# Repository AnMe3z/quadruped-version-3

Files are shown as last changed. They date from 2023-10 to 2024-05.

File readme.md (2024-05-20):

# Мобилен робот с безжично управление
## _MECHKA v3_



Целта на дипломната работа е да се създаде четирикрак робот с безжично управление.

Дипломант:     Андрей Методиев Ежков 12Г Випуск 2024

Ръководител: Владимир Иванов

В текущата репозитория е разделена на:

- hardware/ - четежи, CAD файлове и рендери
- software/ - сорс код на изработката

## hardware/

Тук се намират всички чертежи по корпуса, CAD файлове, рендери и файловете за платката:

- body/
- leg/
- motor/
- schematics/

Както и 3Д рендер на цялостния робот

## software/

Тук се намира сорс кода на проекта

- main/
- main.c
- control-app/
- app.c

main.c е софтуерът за микроконтролера. Инструкции за флашване:

```sh
cd software/main/build
chmod +x upload.sh
./upload.sh
```

app.py е GUI-то за контрол върху робота. Инструкции:

```sh
cd software/control-app/
source venv/bin/activate
python3 app.py
```

## License

Copyright 2023-2024 All rights reserved
Андрей Ежков си запазва всички права

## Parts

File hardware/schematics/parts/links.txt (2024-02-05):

https://app.ultralibrarian.com/details/e938f7e1-4622-11ed-b159-0a34d6323d74/Toshiba-Electronic-Devices-Storage-Corp-/TB67H450AFNG-EL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
https://app.ultralibrarian.com/details/ca52ef32-0283-11ed-b159-0a34d6323d74/Raspberry-Pi/SC0917?uid=129877558
https://grabcad.com/library/xl4005-1
https://grabcad.com/library/raspberry-pi-pico-w-rp2040-no-pins-pins-and-socketed-1
https://app.ultralibrarian.com/details/f9dd745b-0f3c-11ec-9033-0a34d6323d74/Amass/XT60PW-F?open=backlink
https://github.com/sarfat96/KiCad/blob/master/library/Module/XL4005/XL4005_DC-DC.lib
https://app.ultralibrarian.com/details/4b3352ef-44e3-11eb-9033-0a34d6323d74/JST/B7B-XH-A-LF-SN-?uid=7501607
https://app.ultralibrarian.com/details/34553c35-1aab-11e9-ab3a-0a3560a4cccc/JST/B2B-EH-A-LF-SN-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

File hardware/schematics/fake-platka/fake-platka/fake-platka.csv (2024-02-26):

Source: | /home/andrey-shefa/Documents/repos/quadruped-version-3/hardware/schematics/fake-platka/fake-platka/fake-platka.kicad_sch
Date: | Fri 23 Feb 2024 09:56:27 AM EET
Tool: | Eeschema 6.0.11+dfsg-1
Generator: | /usr/share/kicad/plugins/bom_csv_grouped_by_value_with_fp.py
Component Count: | 88
Ref | Qnty | Value | Cmp name | Footprint | Description | Vendor
D1, D2, D3, D4, D5, D6, D7, D8, | 8 | 1N4001 | DIODE | Diode_THT:D_DO-41_SOD81_P7.62mm_Horizontal | Diode symbol for simulation only. Pin order incompatible with official kicad footprints
J1, J2, J7, J8, J14, J15, J21, J22, J28, J29, | 10 | XT60PW-F | XT60PW-F | quadruped-lib-footprints:CONN_XT60PW-F_AMA
J3, J4, J5, J6, J9, J10, J11, J12, J13, J16, J17, J18, J19, J20, J23, J24, J25, J26, J27, J30, | 20 | B2B-EH-A | B2B-EH-A_LFSN | quadruped-lib-footprints:CONN_B2B-EH-A LFSN_JST
R1, R2, R7, R8, R9, R10, R16, R17, R18, R19, R25, R26, R27, R28, R34, R35, R36, R37, | 18 | R1 | R | Resistor_THT:R_Axial_DIN0207_L6.3mm_D2.5mm_P10.16mm_Horizontal | Resistor
R3, R4, R6, R11, R12, R13, R15, R20, R21, R22, R24, R29, R30, R31, R33, R38, | 16 | 5K | R | Resistor_THT:R_Axial_DIN0207_L6.3mm_D2.5mm_P10.16mm_Horizontal | Resistor
R5, R14, R23, R32, | 4 | 150R | R | Resistor_THT:R_Axial_DIN0207_L6.3mm_D2.5mm_P10.16mm_Horizontal | Resistor
U1, U2, | 2 | XL4005 | XL4005 | quadruped-lib-footprints:XL4005_DC-DC
U3, U4, | 2 | SC0915-pico-w-board | SC0915-pico-w-board | quadruped-lib-footprints:RPi_PicoW_SMD_TH
U5, U6, U7, U8, U9, U10, U11, U12, | 8 | TB67H450AFNG_EL | TB67H450AFNG_EL | quadruped-lib-footprints:P-HSOP8-0405-1.27-002_TOS

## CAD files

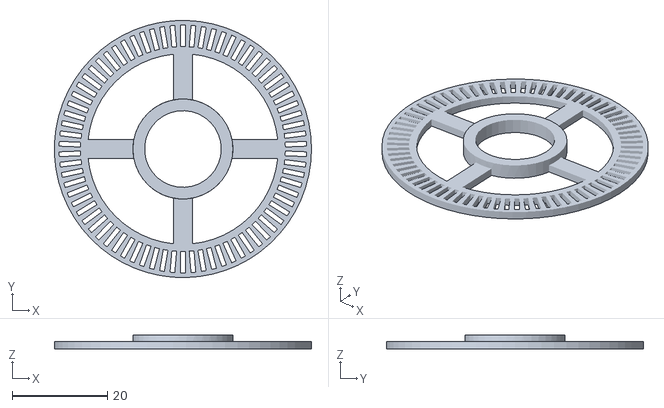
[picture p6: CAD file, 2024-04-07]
hardware/leg/encoder/wingEncoder/wingFullBelt74.stl
54.0 x 54.0 x 3.00

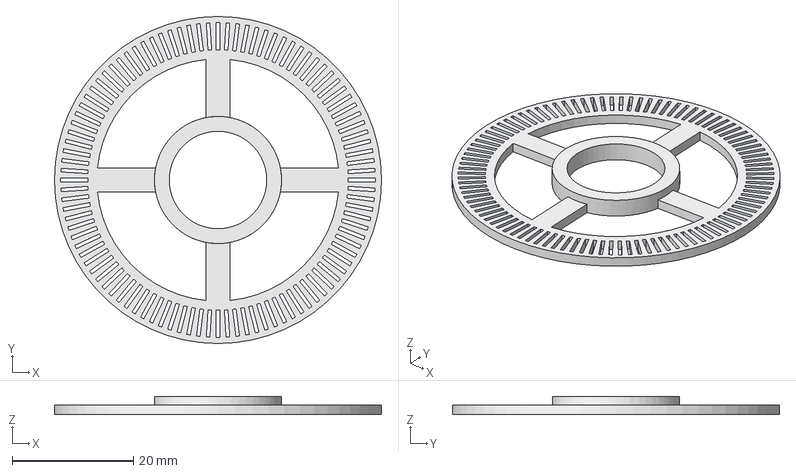
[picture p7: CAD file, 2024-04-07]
hardware/leg/encoder/wingEncoder/wingFullBelt.FCStd
54.0 x 54.0 x 3.00 mm

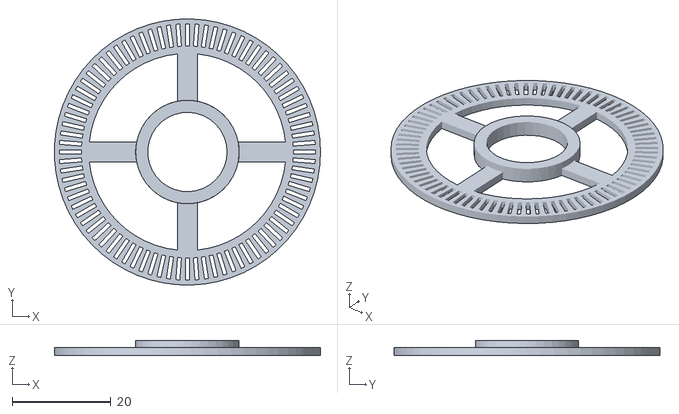
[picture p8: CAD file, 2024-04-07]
hardware/leg/encoder/wingEncoder/wingFullBelt84.stl
54.0 x 54.0 x 3.00

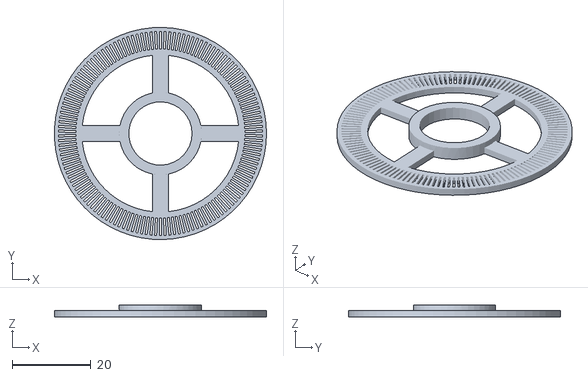
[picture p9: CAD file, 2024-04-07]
hardware/leg/encoder/wingEncoder/wingFullBelt134.stl
54.0 x 54.0 x 3.00

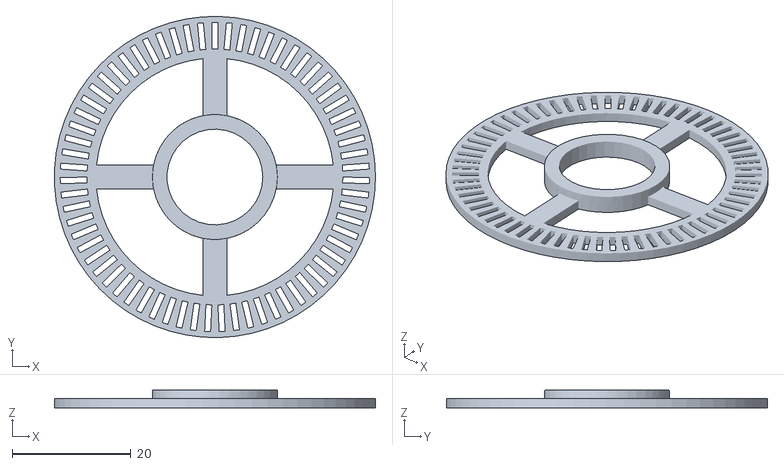
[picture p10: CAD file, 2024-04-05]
hardware/leg/encoder/wingEncoder/wingFullBelt67.stl
54.0 x 54.0 x 3.00

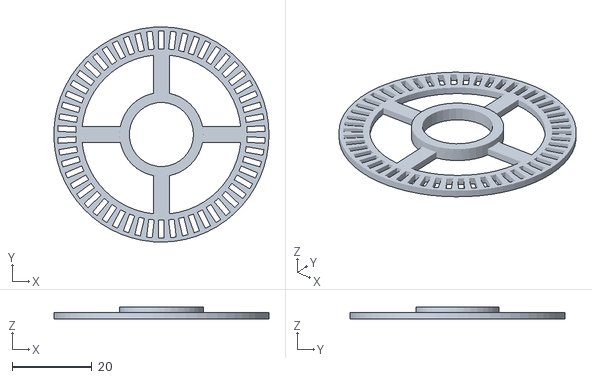
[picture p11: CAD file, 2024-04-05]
hardware/leg/encoder/wingEncoder/wingFullBelt54.stl
54.0 x 54.0 x 3.00

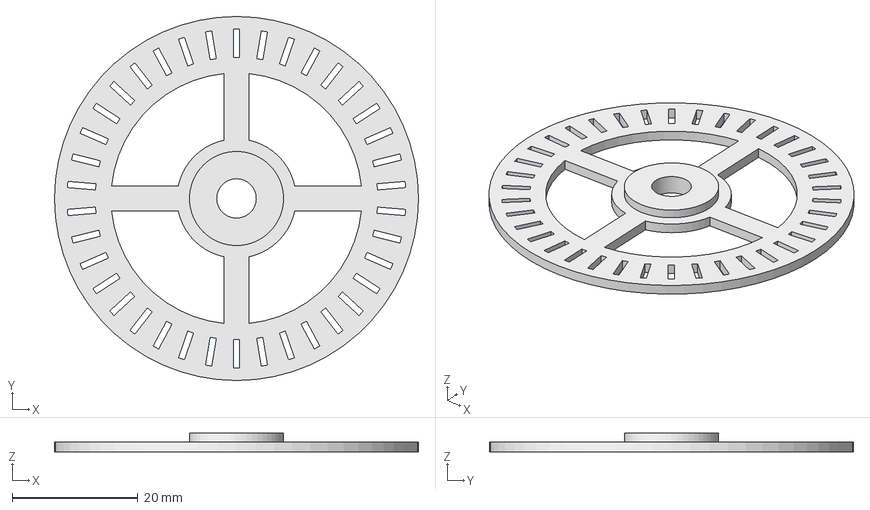
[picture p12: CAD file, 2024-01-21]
hardware/leg/encoder/wingEncoder/wingFull.FCStd
58.0 x 58.0 x 3.00 mm

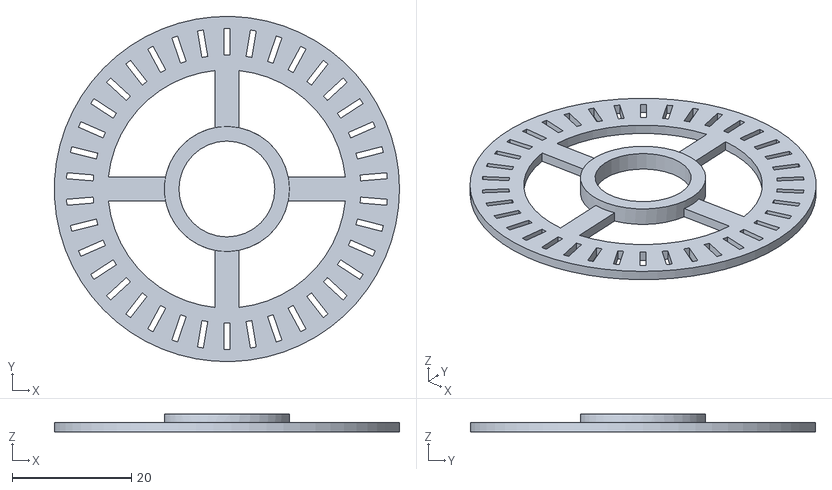
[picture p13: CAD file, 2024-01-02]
hardware/leg/encoder/wingEncoder/wingFullBelt38.stl
58.0 x 58.0 x 3.00

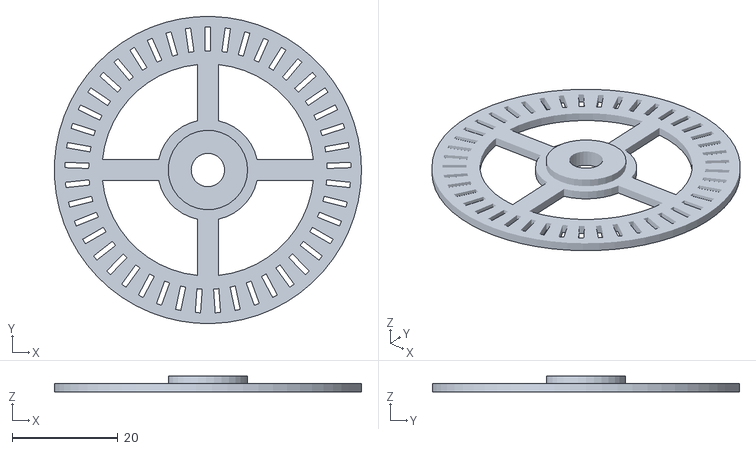
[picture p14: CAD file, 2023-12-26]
hardware/leg/encoder/wingEncoder/wingFull45.stl
58.0 x 58.0 x 3.00

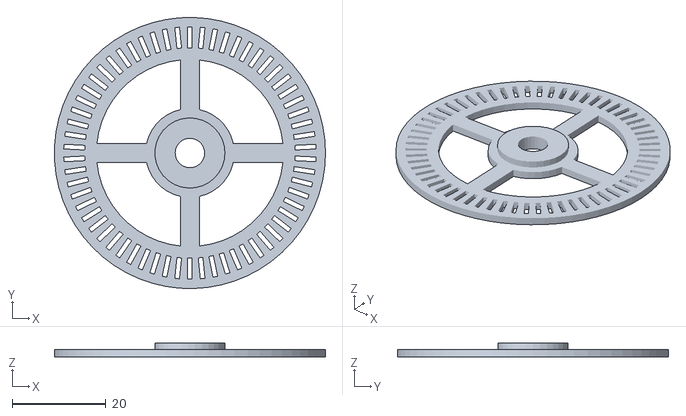
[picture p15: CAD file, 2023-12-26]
hardware/leg/encoder/wingEncoder/wingFull62.stl
58.0 x 58.0 x 3.00

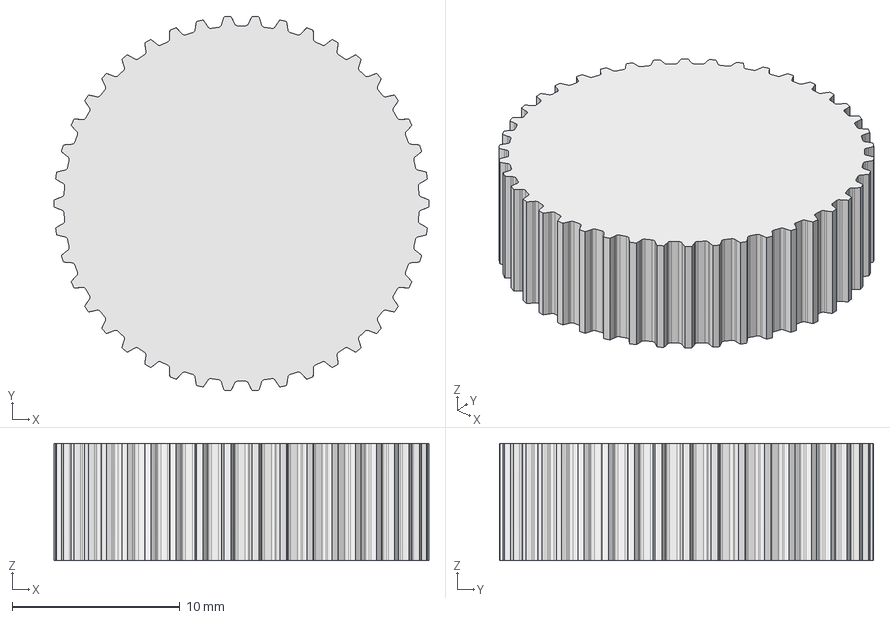
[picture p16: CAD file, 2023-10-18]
belt-gear.FCStd
22.4 x 22.4 x 7.00 mm

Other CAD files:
hardware/leg/encoder/wingEncoder/wingFullBelt100.stl
hardware/leg/knee/mainpoints.FCStd
hardware/leg/encoder/wingEncoder/wingFullBelt38Cut.stl
hardware/leg/encoder/wingEncoder/wingFull37.stl
hardware/leg/encoder/wingEncoder/wingFull38.stl
hardware/leg/encoder/wingEncoder/wingFull36.stl
hardware/leg/encoder/wingEncoder/wingFull34.stl
encoder/base.FCStd
encoder/encoder-wheels/encoder-wheel-8-1mm.FCStd
encoder/encoder-wheels/encoder-wheel-8-1mm.stl
encoder/encoder-wheels/encoder-wheel-8-3mm.FCStd
encoder/encoder-wheels/encoder-wheel-8-3mm.stl
encoder/encoder-wheels/encoder-wheel.FCStd
encoder/encoder-wheels/ew-16-1mm.FCStd
encoder/encoder-wheels/ew-16-1mm.stl
encoder/gears/encoder-gear-Body.stl
encoder/gears/encoder-gear.FCStd
encoder/gears/mid-gear-arm-Body.stl
encoder/gears/mid-gear-arm.FCStd
encoder/gears/middle-gear-Body.stl
encoder/gears/middle-gear.FCStd
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

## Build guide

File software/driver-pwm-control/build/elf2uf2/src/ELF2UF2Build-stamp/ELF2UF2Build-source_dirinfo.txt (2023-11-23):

# This is a generated file and its contents are an internal implementation detail.
# The download step will be re-executed if anything in this file changes.
# No other meaning or use of this file is supported.

method=source_dir
command=
source_dir=/home/andrey-shefa/pico/pico-sdk/tools/elf2uf2
work_dir=

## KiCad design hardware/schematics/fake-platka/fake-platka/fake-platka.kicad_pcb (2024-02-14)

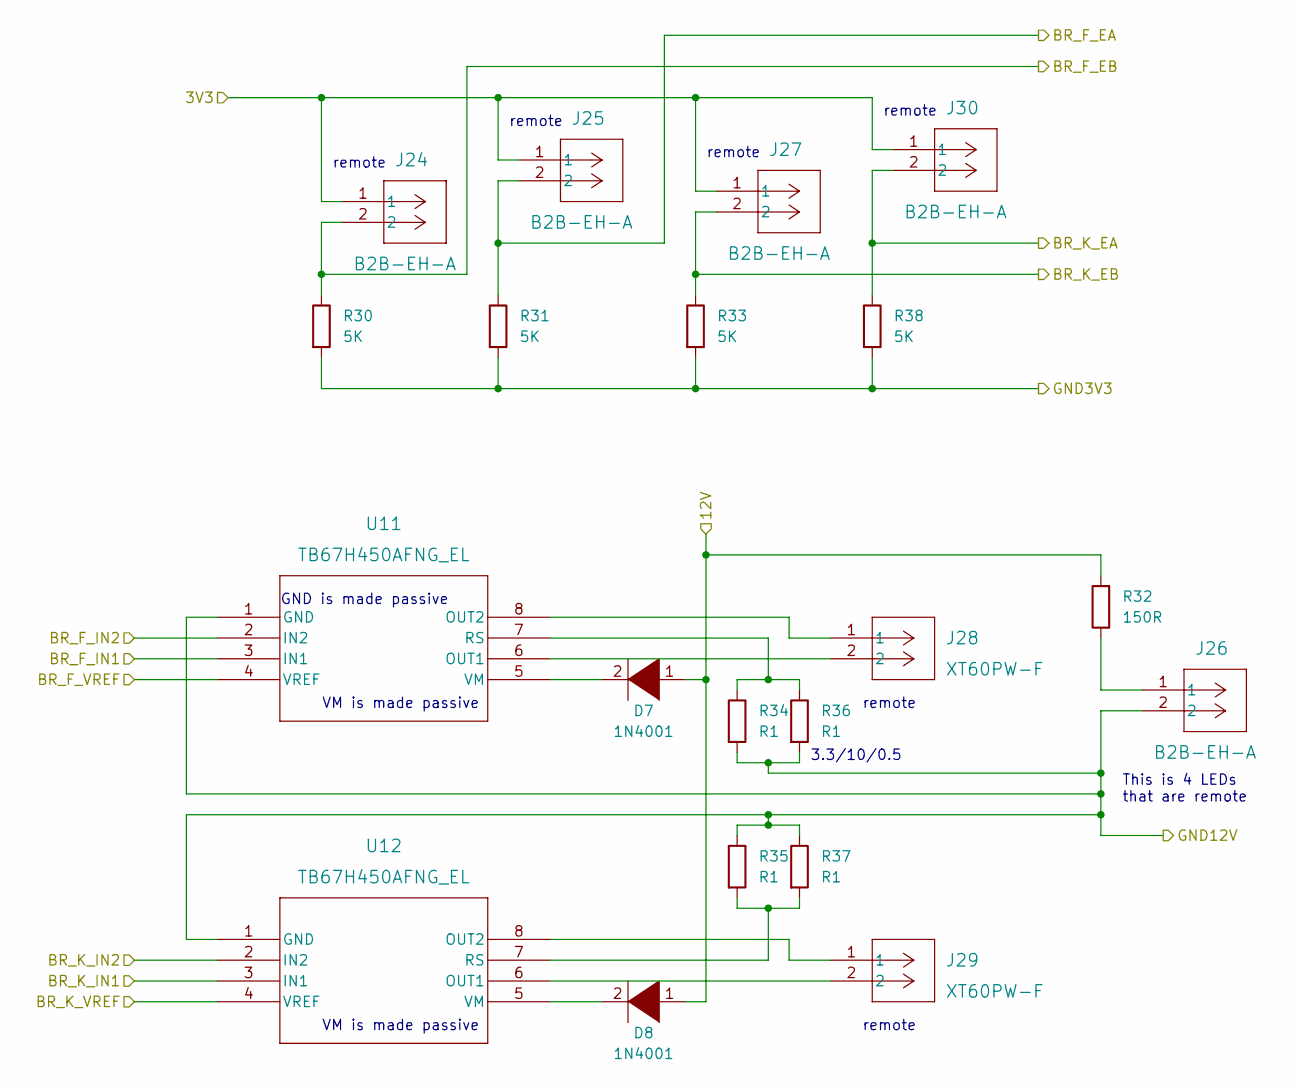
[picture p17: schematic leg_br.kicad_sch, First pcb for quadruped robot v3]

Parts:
D7, D8: 1N4001; D_DO-41_SOD81_P7.62mm_Horizontal
J24, J25, J26, J27, J30: B2B-EH-A; CONN_B2B-EH-A LFSN_JST
J28, J29: XT60PW-F; CONN_XT60PW-F_AMA
R30, R31, R33, R38: 5K; R_Axial_DIN0207_L6.3mm_D2.5mm_P10.16mm_Horizontal
R32: 150R; R_Axial_DIN0207_L6.3mm_D2.5mm_P10.16mm_Horizontal
R34, R35, R36, R37: R1; R_Axial_DIN0207_L6.3mm_D2.5mm_P10.16mm_Horizontal
U11, U12: TB67H450AFNG_EL; P-HSOP8-0405-1.27-002_TOS

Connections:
/Left Controller /3V3: J24.1, J25.1, J27.1, J30.1; also elsewhere on the board
/Left Controller /GND3V3: R30.2, R31.2, R33.2, R38.2; also elsewhere on the board
/Leg Back Left/12V: D7.1 (K), D8.1 (K), R32.2; also elsewhere on the board
/Leg Back Right/BR_F_EA: J25.2, R31.1; also elsewhere on the board
/Leg Back Right/BR_F_EB: J24.2, R30.1; also elsewhere on the board
/Leg Back Right/BR_F_IN1: U11.3 (IN1); also elsewhere on the board
/Leg Back Right/BR_F_IN2: U11.2 (IN2); also elsewhere on the board
/Leg Back Right/BR_F_VREF: U11.4 (VREF), U12.4 (VREF); also elsewhere on the board
/Leg Back Right/BR_K_EA: J30.2, R38.1; also elsewhere on the board
/Leg Back Right/BR_K_EB: J27.2, R33.1; also elsewhere on the board
/Leg Back Right/BR_K_IN1: U12.3 (IN1); also elsewhere on the board
/Leg Back Right/BR_K_IN2: U12.2 (IN2); also elsewhere on the board
/Leg Back Right/GND12V: J26.2, R34.2, R35.1, R36.2, R37.1, U11.1 (GND), U12.1 (GND); also elsewhere on the board
unnamed: D7.2 (A), U11.5 (VM)
unnamed: D8.2 (A), U12.5 (VM)
unnamed: J26.1, R32.1
unnamed: J28.1, U11.8 (OUT2)
unnamed: J28.2, U11.6 (OUT1)
unnamed: J29.1, U12.8 (OUT2)
unnamed: J29.2, U12.6 (OUT1)
unnamed: R34.1, R36.1, U11.7 (RS)
unnamed: R35.2, R37.2, U12.7 (RS)

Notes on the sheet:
GND is made passive
remote
This is 4 LEDs that are remote
VM is made passive
3.3/10/0.5

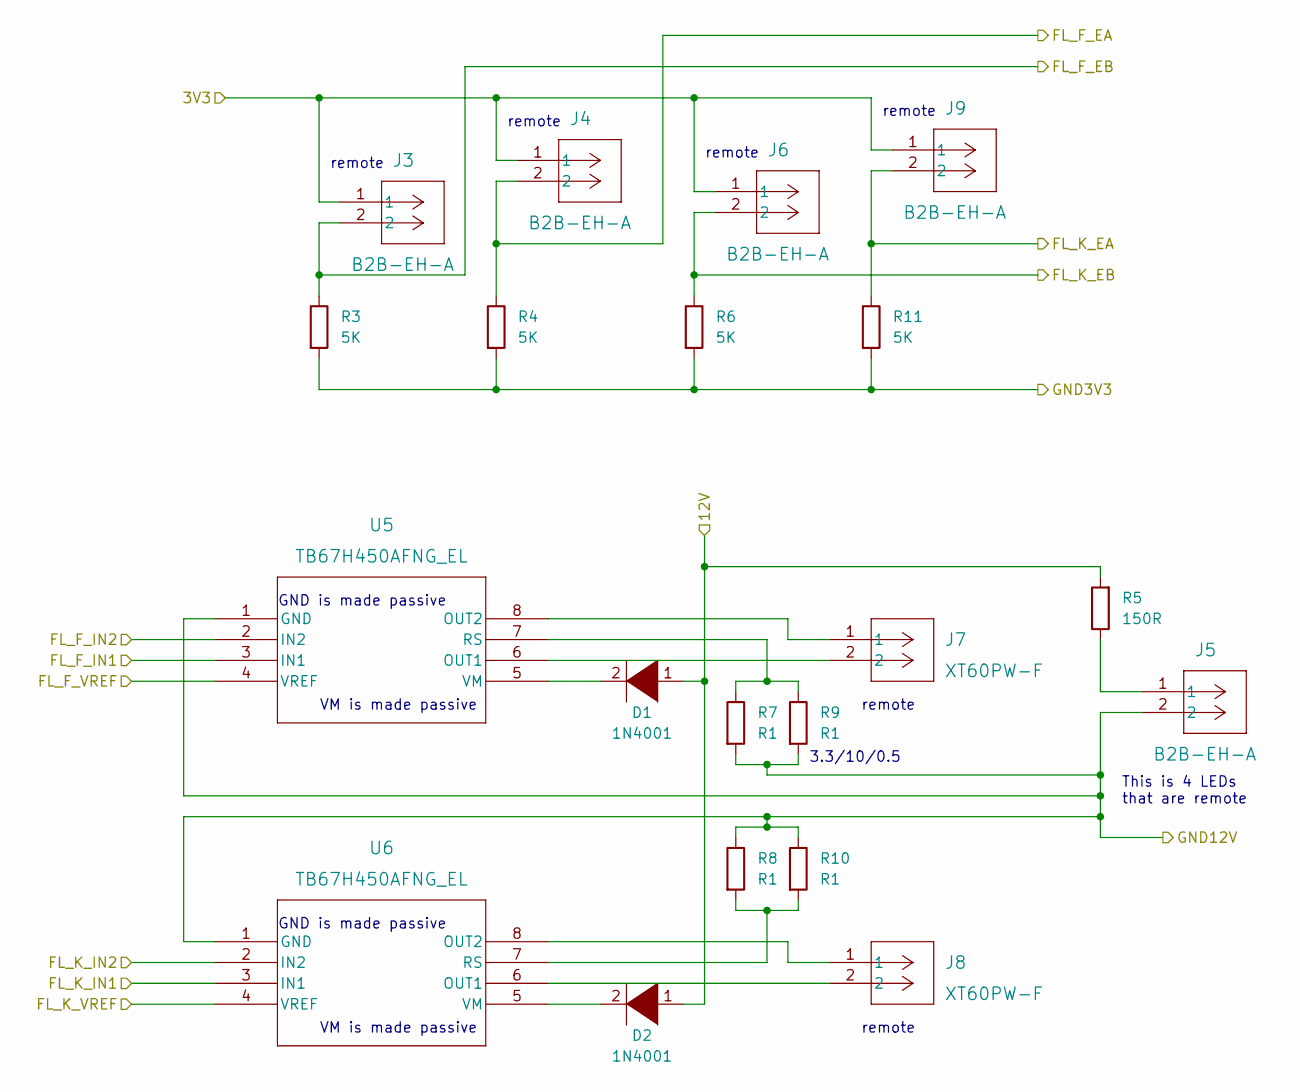
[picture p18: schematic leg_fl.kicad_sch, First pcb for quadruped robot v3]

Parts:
D1, D2: 1N4001; D_DO-41_SOD81_P7.62mm_Horizontal
J3, J4, J5, J6, J9: B2B-EH-A; CONN_B2B-EH-A LFSN_JST
J7, J8: XT60PW-F; CONN_XT60PW-F_AMA
R3, R4, R6, R11: 5K; R_Axial_DIN0207_L6.3mm_D2.5mm_P10.16mm_Horizontal
R5: 150R; R_Axial_DIN0207_L6.3mm_D2.5mm_P10.16mm_Horizontal
R7, R8, R9, R10: R1; R_Axial_DIN0207_L6.3mm_D2.5mm_P10.16mm_Horizontal
U5, U6: TB67H450AFNG_EL; P-HSOP8-0405-1.27-002_TOS

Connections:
/Left Controller /3V3: J3.1, J4.1, J6.1, J9.1; also elsewhere on the board
/Left Controller /3V3_VREF: U5.4 (VREF), U6.4 (VREF); also elsewhere on the board
/Left Controller /FL_F_EA: J4.2, R4.1; also elsewhere on the board
/Left Controller /FL_F_EB: J3.2, R3.1; also elsewhere on the board
/Left Controller /FL_F_IN1: U5.3 (IN1); also elsewhere on the board
/Left Controller /FL_F_IN2: U5.2 (IN2); also elsewhere on the board
/Left Controller /FL_K_EA: J9.2, R11.1; also elsewhere on the board
/Left Controller /FL_K_EB: J6.2, R6.1; also elsewhere on the board
/Left Controller /FL_K_IN1: U6.3 (IN1); also elsewhere on the board
/Left Controller /FL_K_IN2: U6.2 (IN2); also elsewhere on the board
/Left Controller /GND3V3: R3.2, R4.2, R6.2, R11.2; also elsewhere on the board
/Leg Back Left/12V: D1.1 (K), D2.1 (K), J5.2, R5.2, R7.2, R8.1, R9.2, R10.1, U5.1 (GND), U6.1 (GND); also elsewhere on the board
unnamed: D1.2 (A), U5.5 (VM)
unnamed: D2.2 (A), U6.5 (VM)
unnamed: J5.1, R5.1
unnamed: J7.1, U5.8 (OUT2)
unnamed: J7.2, U5.6 (OUT1)
unnamed: J8.1, U6.8 (OUT2)
unnamed: J8.2, U6.6 (OUT1)
unnamed: R7.1, R9.1, U5.7 (RS)
unnamed: R8.2, R10.2, U6.7 (RS)

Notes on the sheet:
remote
VM is made passive
GND is made passive
This is 4 LEDs that are remote
3.3/10/0.5

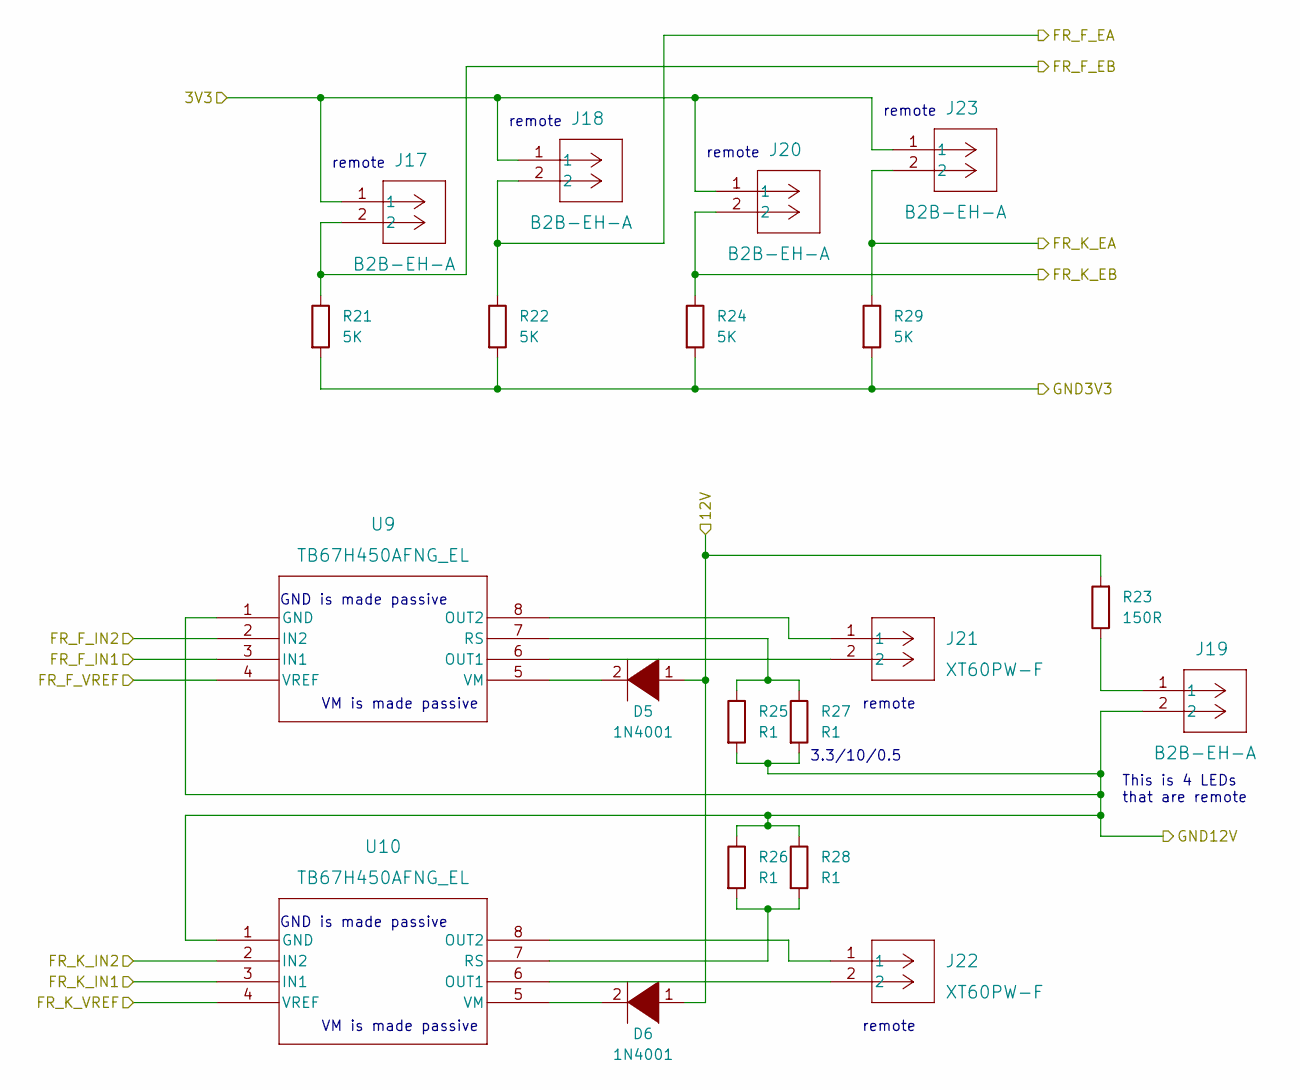
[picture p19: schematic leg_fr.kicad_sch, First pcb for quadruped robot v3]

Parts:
D5, D6: 1N4001; D_DO-41_SOD81_P7.62mm_Horizontal
J17, J18, J19, J20, J23: B2B-EH-A; CONN_B2B-EH-A LFSN_JST
J21, J22: XT60PW-F; CONN_XT60PW-F_AMA
R21, R22, R24, R29: 5K; R_Axial_DIN0207_L6.3mm_D2.5mm_P10.16mm_Horizontal
R23: 150R; R_Axial_DIN0207_L6.3mm_D2.5mm_P10.16mm_Horizontal
R25, R26, R27, R28: R1; R_Axial_DIN0207_L6.3mm_D2.5mm_P10.16mm_Horizontal
U9, U10: TB67H450AFNG_EL; P-HSOP8-0405-1.27-002_TOS

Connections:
/Left Controller /3V3: J17.1, J18.1, J20.1, J23.1; also elsewhere on the board
/Left Controller /GND3V3: R21.2, R22.2, R24.2, R29.2; also elsewhere on the board
/Leg Back Left/12V: D5.1 (K), D6.1 (K), R23.2; also elsewhere on the board
/Leg Back Right/BR_F_VREF: U9.4 (VREF), U10.4 (VREF); also elsewhere on the board
/Leg Back Right/GND12V: J19.2, R25.2, R26.1, R27.2, R28.1, U9.1 (GND), U10.1 (GND); also elsewhere on the board
/Leg Front Right/FR_F_EA: J18.2, R22.1; also elsewhere on the board
/Leg Front Right/FR_F_EB: J17.2, R21.1; also elsewhere on the board
/Leg Front Right/FR_F_IN1: U9.3 (IN1); also elsewhere on the board
/Leg Front Right/FR_F_IN2: U9.2 (IN2); also elsewhere on the board
/Leg Front Right/FR_K_EA: J23.2, R29.1; also elsewhere on the board
/Leg Front Right/FR_K_EB: J20.2, R24.1; also elsewhere on the board
/Leg Front Right/FR_K_IN1: U10.3 (IN1); also elsewhere on the board
/Leg Front Right/FR_K_IN2: U10.2 (IN2); also elsewhere on the board
unnamed: D5.2 (A), U9.5 (VM)
unnamed: D6.2 (A), U10.5 (VM)
unnamed: J21.1, U9.8 (OUT2)
unnamed: J21.2, U9.6 (OUT1)
unnamed: J22.1, U10.8 (OUT2)
unnamed: J22.2, U10.6 (OUT1)
unnamed: J19.1, R23.1
unnamed: R25.1, R27.1, U9.7 (RS)
unnamed: R26.2, R28.2, U10.7 (RS)

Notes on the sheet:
This is 4 LEDs that are remote
GND is made passive
3.3/10/0.5
remote
VM is made passive

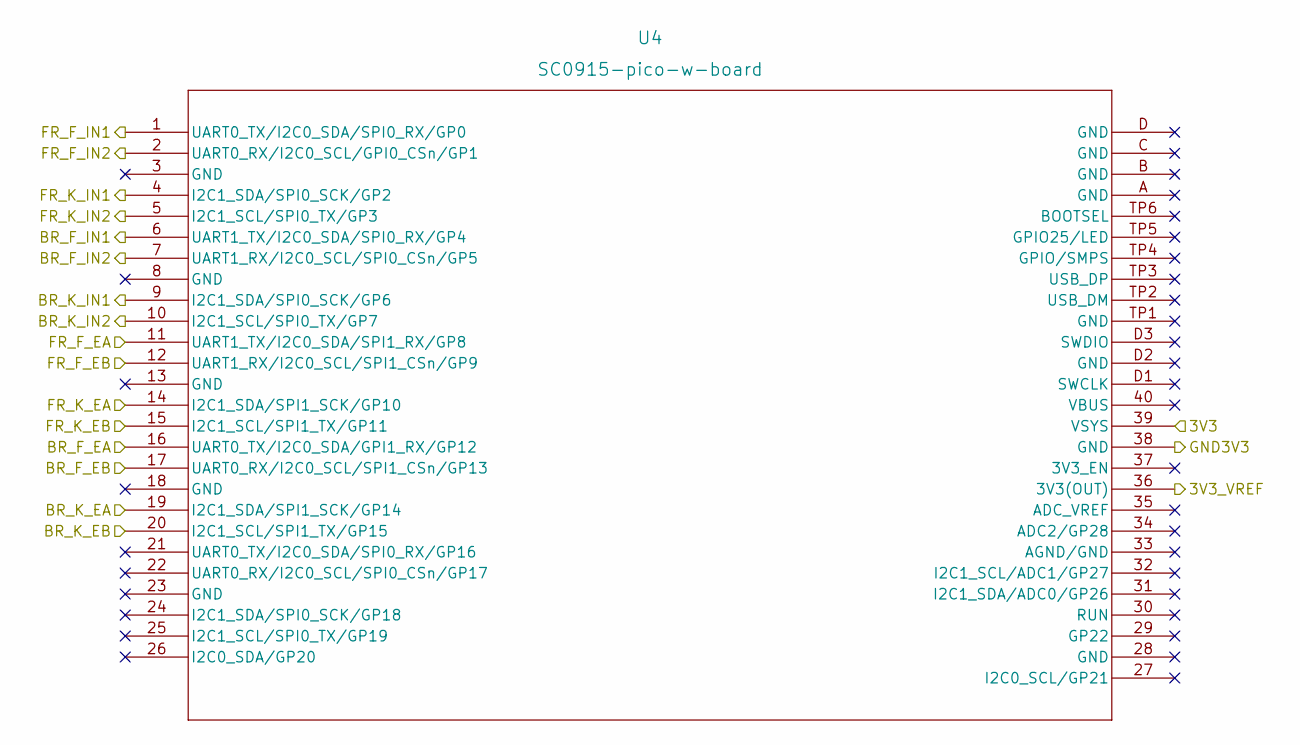
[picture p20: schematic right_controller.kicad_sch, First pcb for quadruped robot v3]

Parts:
U4: SC0915-pico-w-board; RPi_PicoW_SMD_TH

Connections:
/Left Controller /3V3: U4.39 (VSYS); also elsewhere on the board
/Left Controller /GND3V3: U4.38 (GND); also elsewhere on the board
/Leg Back Right/BR_F_EA: U4.16 (UART0_TX/I2C0_SDA/GPI1_RX/GP12); also elsewhere on the board
/Leg Back Right/BR_F_EB: U4.17 (UART0_RX/I2C0_SCL/SPI1_CSn/GP13); also elsewhere on the board
/Leg Back Right/BR_F_IN1: U4.6 (UART1_TX/I2C0_SDA/SPI0_RX/GP4); also elsewhere on the board
/Leg Back Right/BR_F_IN2: U4.7 (UART1_RX/I2C0_SCL/SPI0_CSn/GP5); also elsewhere on the board
/Leg Back Right/BR_F_VREF: U4.36 (3V3(OUT)); also elsewhere on the board
/Leg Back Right/BR_K_EA: U4.19 (I2C1_SDA/SPI1_SCK/GP14); also elsewhere on the board
/Leg Back Right/BR_K_EB: U4.20 (I2C1_SCL/SPI1_TX/GP15); also elsewhere on the board
/Leg Back Right/BR_K_IN1: U4.9 (I2C1_SDA/SPI0_SCK/GP6); also elsewhere on the board
/Leg Back Right/BR_K_IN2: U4.10 (I2C1_SCL/SPI0_TX/GP7); also elsewhere on the board
/Leg Front Right/FR_F_EA: U4.11 (UART1_TX/I2C0_SDA/SPI1_RX/GP8); also elsewhere on the board
/Leg Front Right/FR_F_EB: U4.12 (UART1_RX/I2C0_SCL/SPI1_CSn/GP9); also elsewhere on the board
/Leg Front Right/FR_F_IN1: U4.1 (UART0_TX/I2C0_SDA/SPI0_RX/GP0); also elsewhere on the board
/Leg Front Right/FR_F_IN2: U4.2 (UART0_RX/I2C0_SCL/GPI0_CSn/GP1); also elsewhere on the board
/Leg Front Right/FR_K_EA: U4.14 (I2C1_SDA/SPI1_SCK/GP10); also elsewhere on the board
/Leg Front Right/FR_K_EB: U4.15 (I2C1_SCL/SPI1_TX/GP11); also elsewhere on the board
/Leg Front Right/FR_K_IN1: U4.4 (I2C1_SDA/SPI0_SCK/GP2); also elsewhere on the board
/Leg Front Right/FR_K_IN2: U4.5 (I2C1_SCL/SPI0_TX/GP3); also elsewhere on the board

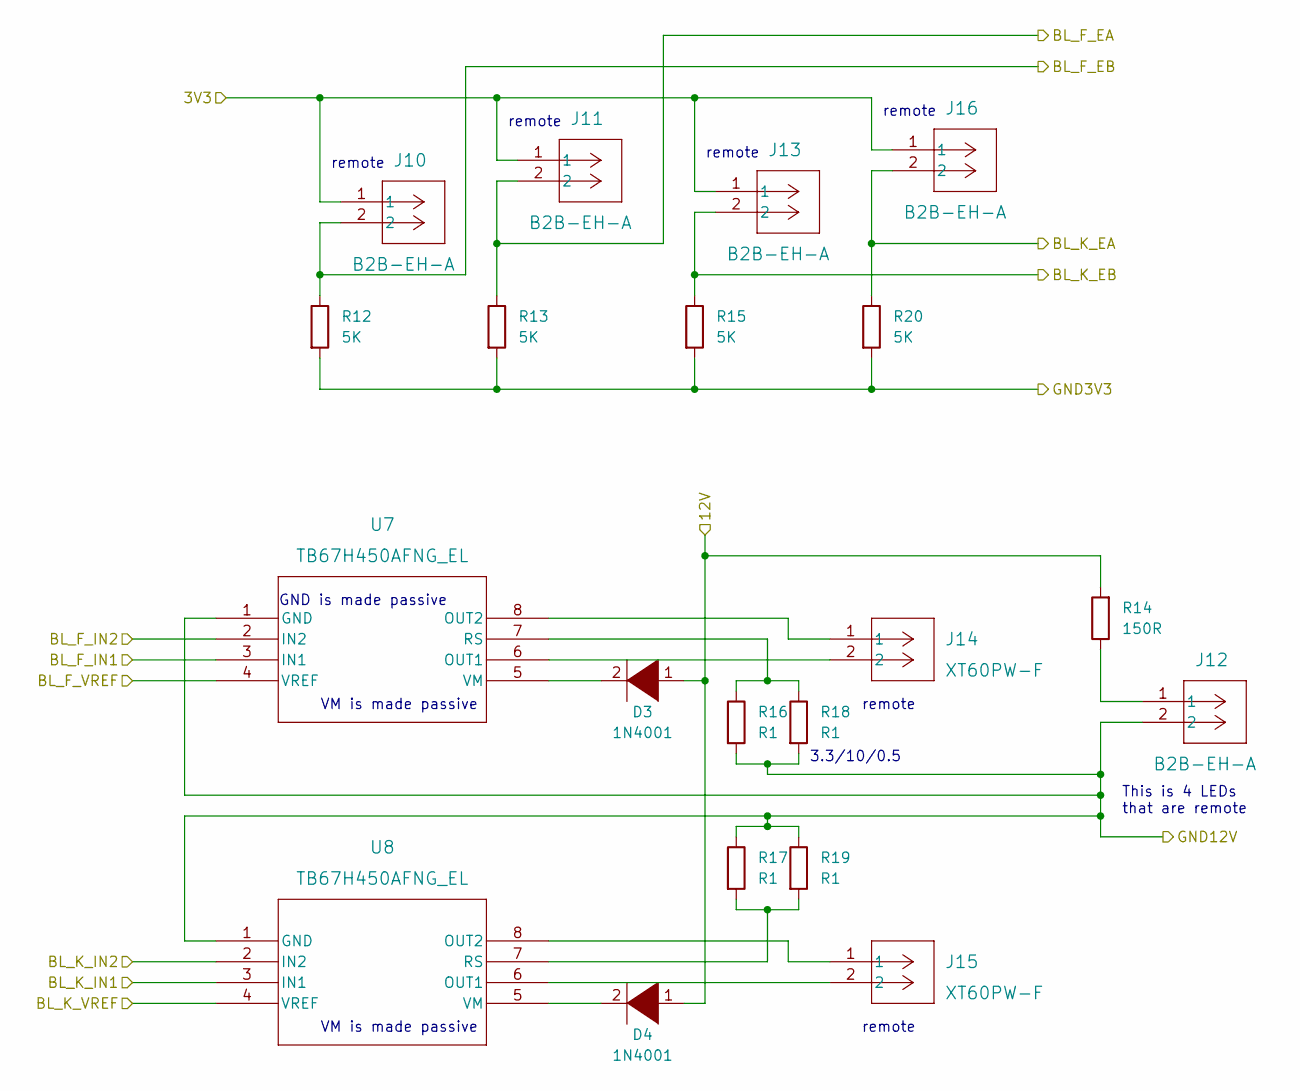
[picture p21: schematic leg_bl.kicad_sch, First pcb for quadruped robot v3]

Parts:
D3, D4: 1N4001; D_DO-41_SOD81_P7.62mm_Horizontal
J10, J11, J12, J13, J16: B2B-EH-A; CONN_B2B-EH-A LFSN_JST
J14, J15: XT60PW-F; CONN_XT60PW-F_AMA
R12, R13, R15, R20: 5K; R_Axial_DIN0207_L6.3mm_D2.5mm_P10.16mm_Horizontal
R14: 150R; R_Axial_DIN0207_L6.3mm_D2.5mm_P10.16mm_Horizontal
R16, R17, R18, R19: R1; R_Axial_DIN0207_L6.3mm_D2.5mm_P10.16mm_Horizontal
U7, U8: TB67H450AFNG_EL; P-HSOP8-0405-1.27-002_TOS

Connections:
/Left Controller /3V3: J10.1, J11.1, J13.1, J16.1; also elsewhere on the board
/Left Controller /3V3_VREF: U7.4 (VREF), U8.4 (VREF); also elsewhere on the board
/Left Controller /BL_F_EA: J11.2, R13.1; also elsewhere on the board
/Left Controller /BL_F_EB: J10.2, R12.1; also elsewhere on the board
/Left Controller /BL_F_IN1: U7.3 (IN1); also elsewhere on the board
/Left Controller /BL_F_IN2: U7.2 (IN2); also elsewhere on the board
/Left Controller /BL_K_EA: J16.2, R20.1; also elsewhere on the board
/Left Controller /BL_K_EB: J13.2, R15.1; also elsewhere on the board
/Left Controller /BL_K_IN1: U8.3 (IN1); also elsewhere on the board
/Left Controller /BL_K_IN2: U8.2 (IN2); also elsewhere on the board
/Left Controller /GND3V3: R12.2, R13.2, R15.2, R20.2; also elsewhere on the board
/Leg Back Left/12V: D3.1 (K), D4.1 (K), J12.2, R14.2, R16.2, R17.1, R18.2, R19.1, U7.1 (GND), U8.1 (GND); also elsewhere on the board
unnamed: D3.2 (A), U7.5 (VM)
unnamed: D4.2 (A), U8.5 (VM)
unnamed: J14.1, U7.8 (OUT2)
unnamed: J14.2, U7.6 (OUT1)
unnamed: J15.1, U8.8 (OUT2)
unnamed: J15.2, U8.6 (OUT1)
unnamed: J12.1, R14.1
unnamed: R16.1, R18.1, U7.7 (RS)
unnamed: R17.2, R19.2, U8.7 (RS)

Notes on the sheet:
remote
VM is made passive
GND is made passive
3.3/10/0.5
This is 4 LEDs that are remote

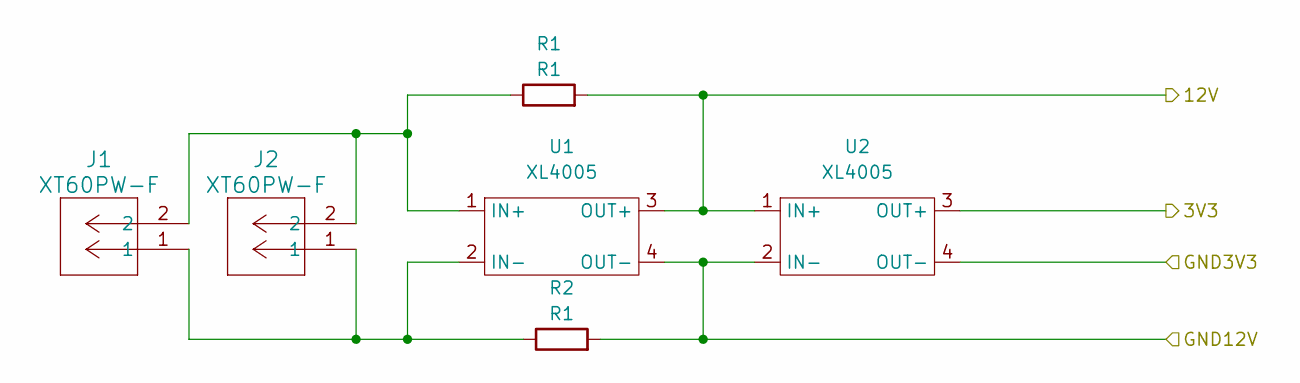
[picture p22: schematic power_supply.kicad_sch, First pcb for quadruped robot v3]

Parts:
J1, J2: XT60PW-F; CONN_XT60PW-F_AMA
R1, R2: R1; R_Axial_DIN0207_L6.3mm_D2.5mm_P10.16mm_Horizontal
U1, U2: XL4005; XL4005_DC-DC

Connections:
/Left Controller /3V3: U2.3 (OUT+); also elsewhere on the board
/Left Controller /GND3V3: U2.4 (OUT-); also elsewhere on the board
/Leg Back Left/12V: R1.2, U1.3 (OUT+), U2.1 (IN+); also elsewhere on the board
/Leg Back Right/GND12V: R2.2, U1.4 (OUT-), U2.2 (IN-); also elsewhere on the board
unnamed: J1.1, J2.1, R2.1, U1.2 (IN-)
unnamed: J1.2, J2.2, R1.1, U1.1 (IN+)

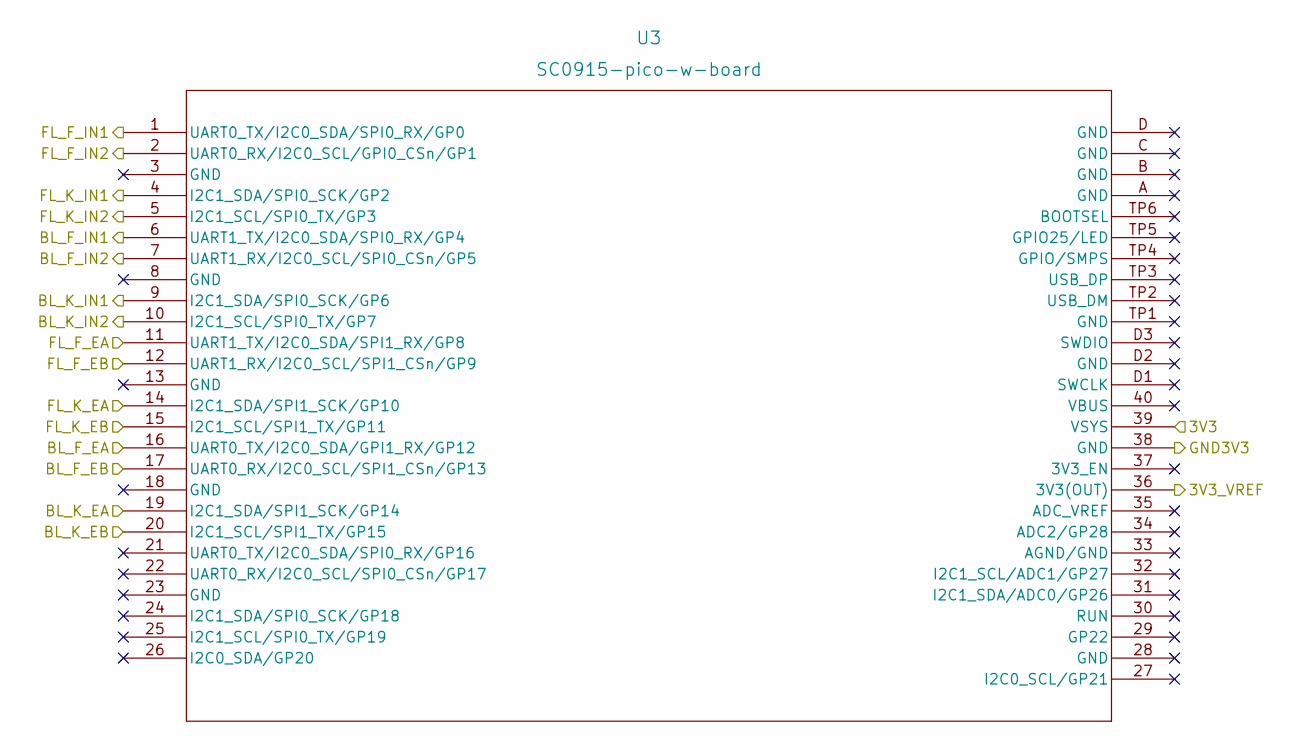
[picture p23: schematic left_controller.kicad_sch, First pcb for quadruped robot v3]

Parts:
U3: SC0915-pico-w-board; RPi_PicoW_SMD_TH

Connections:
/Left Controller /3V3: U3.39 (VSYS); also elsewhere on the board
/Left Controller /3V3_VREF: U3.36 (3V3(OUT)); also elsewhere on the board
/Left Controller /BL_F_EA: U3.16 (UART0_TX/I2C0_SDA/GPI1_RX/GP12); also elsewhere on the board
/Left Controller /BL_F_EB: U3.17 (UART0_RX/I2C0_SCL/SPI1_CSn/GP13); also elsewhere on the board
/Left Controller /BL_F_IN1: U3.6 (UART1_TX/I2C0_SDA/SPI0_RX/GP4); also elsewhere on the board
/Left Controller /BL_F_IN2: U3.7 (UART1_RX/I2C0_SCL/SPI0_CSn/GP5); also elsewhere on the board
/Left Controller /BL_K_EA: U3.19 (I2C1_SDA/SPI1_SCK/GP14); also elsewhere on the board
/Left Controller /BL_K_EB: U3.20 (I2C1_SCL/SPI1_TX/GP15); also elsewhere on the board
/Left Controller /BL_K_IN1: U3.9 (I2C1_SDA/SPI0_SCK/GP6); also elsewhere on the board
/Left Controller /BL_K_IN2: U3.10 (I2C1_SCL/SPI0_TX/GP7); also elsewhere on the board
/Left Controller /FL_F_EA: U3.11 (UART1_TX/I2C0_SDA/SPI1_RX/GP8); also elsewhere on the board
/Left Controller /FL_F_EB: U3.12 (UART1_RX/I2C0_SCL/SPI1_CSn/GP9); also elsewhere on the board
/Left Controller /FL_F_IN1: U3.1 (UART0_TX/I2C0_SDA/SPI0_RX/GP0); also elsewhere on the board
/Left Controller /FL_F_IN2: U3.2 (UART0_RX/I2C0_SCL/GPI0_CSn/GP1); also elsewhere on the board
/Left Controller /FL_K_EA: U3.14 (I2C1_SDA/SPI1_SCK/GP10); also elsewhere on the board
/Left Controller /FL_K_EB: U3.15 (I2C1_SCL/SPI1_TX/GP11); also elsewhere on the board
/Left Controller /FL_K_IN1: U3.4 (I2C1_SDA/SPI0_SCK/GP2); also elsewhere on the board
/Left Controller /FL_K_IN2: U3.5 (I2C1_SCL/SPI0_TX/GP3); also elsewhere on the board
/Left Controller /GND3V3: U3.38 (GND); also elsewhere on the board

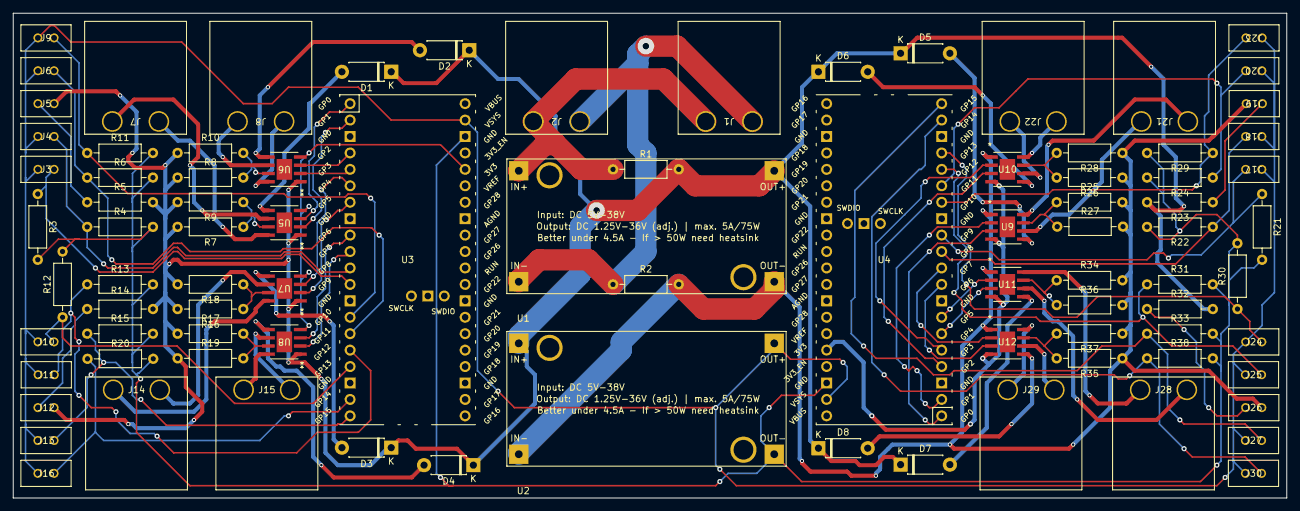
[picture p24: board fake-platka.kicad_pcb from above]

Board: 2 copper layers, 196.9 x 74.9 mm, 88 parts (0 on the bottom side), 76 nets.

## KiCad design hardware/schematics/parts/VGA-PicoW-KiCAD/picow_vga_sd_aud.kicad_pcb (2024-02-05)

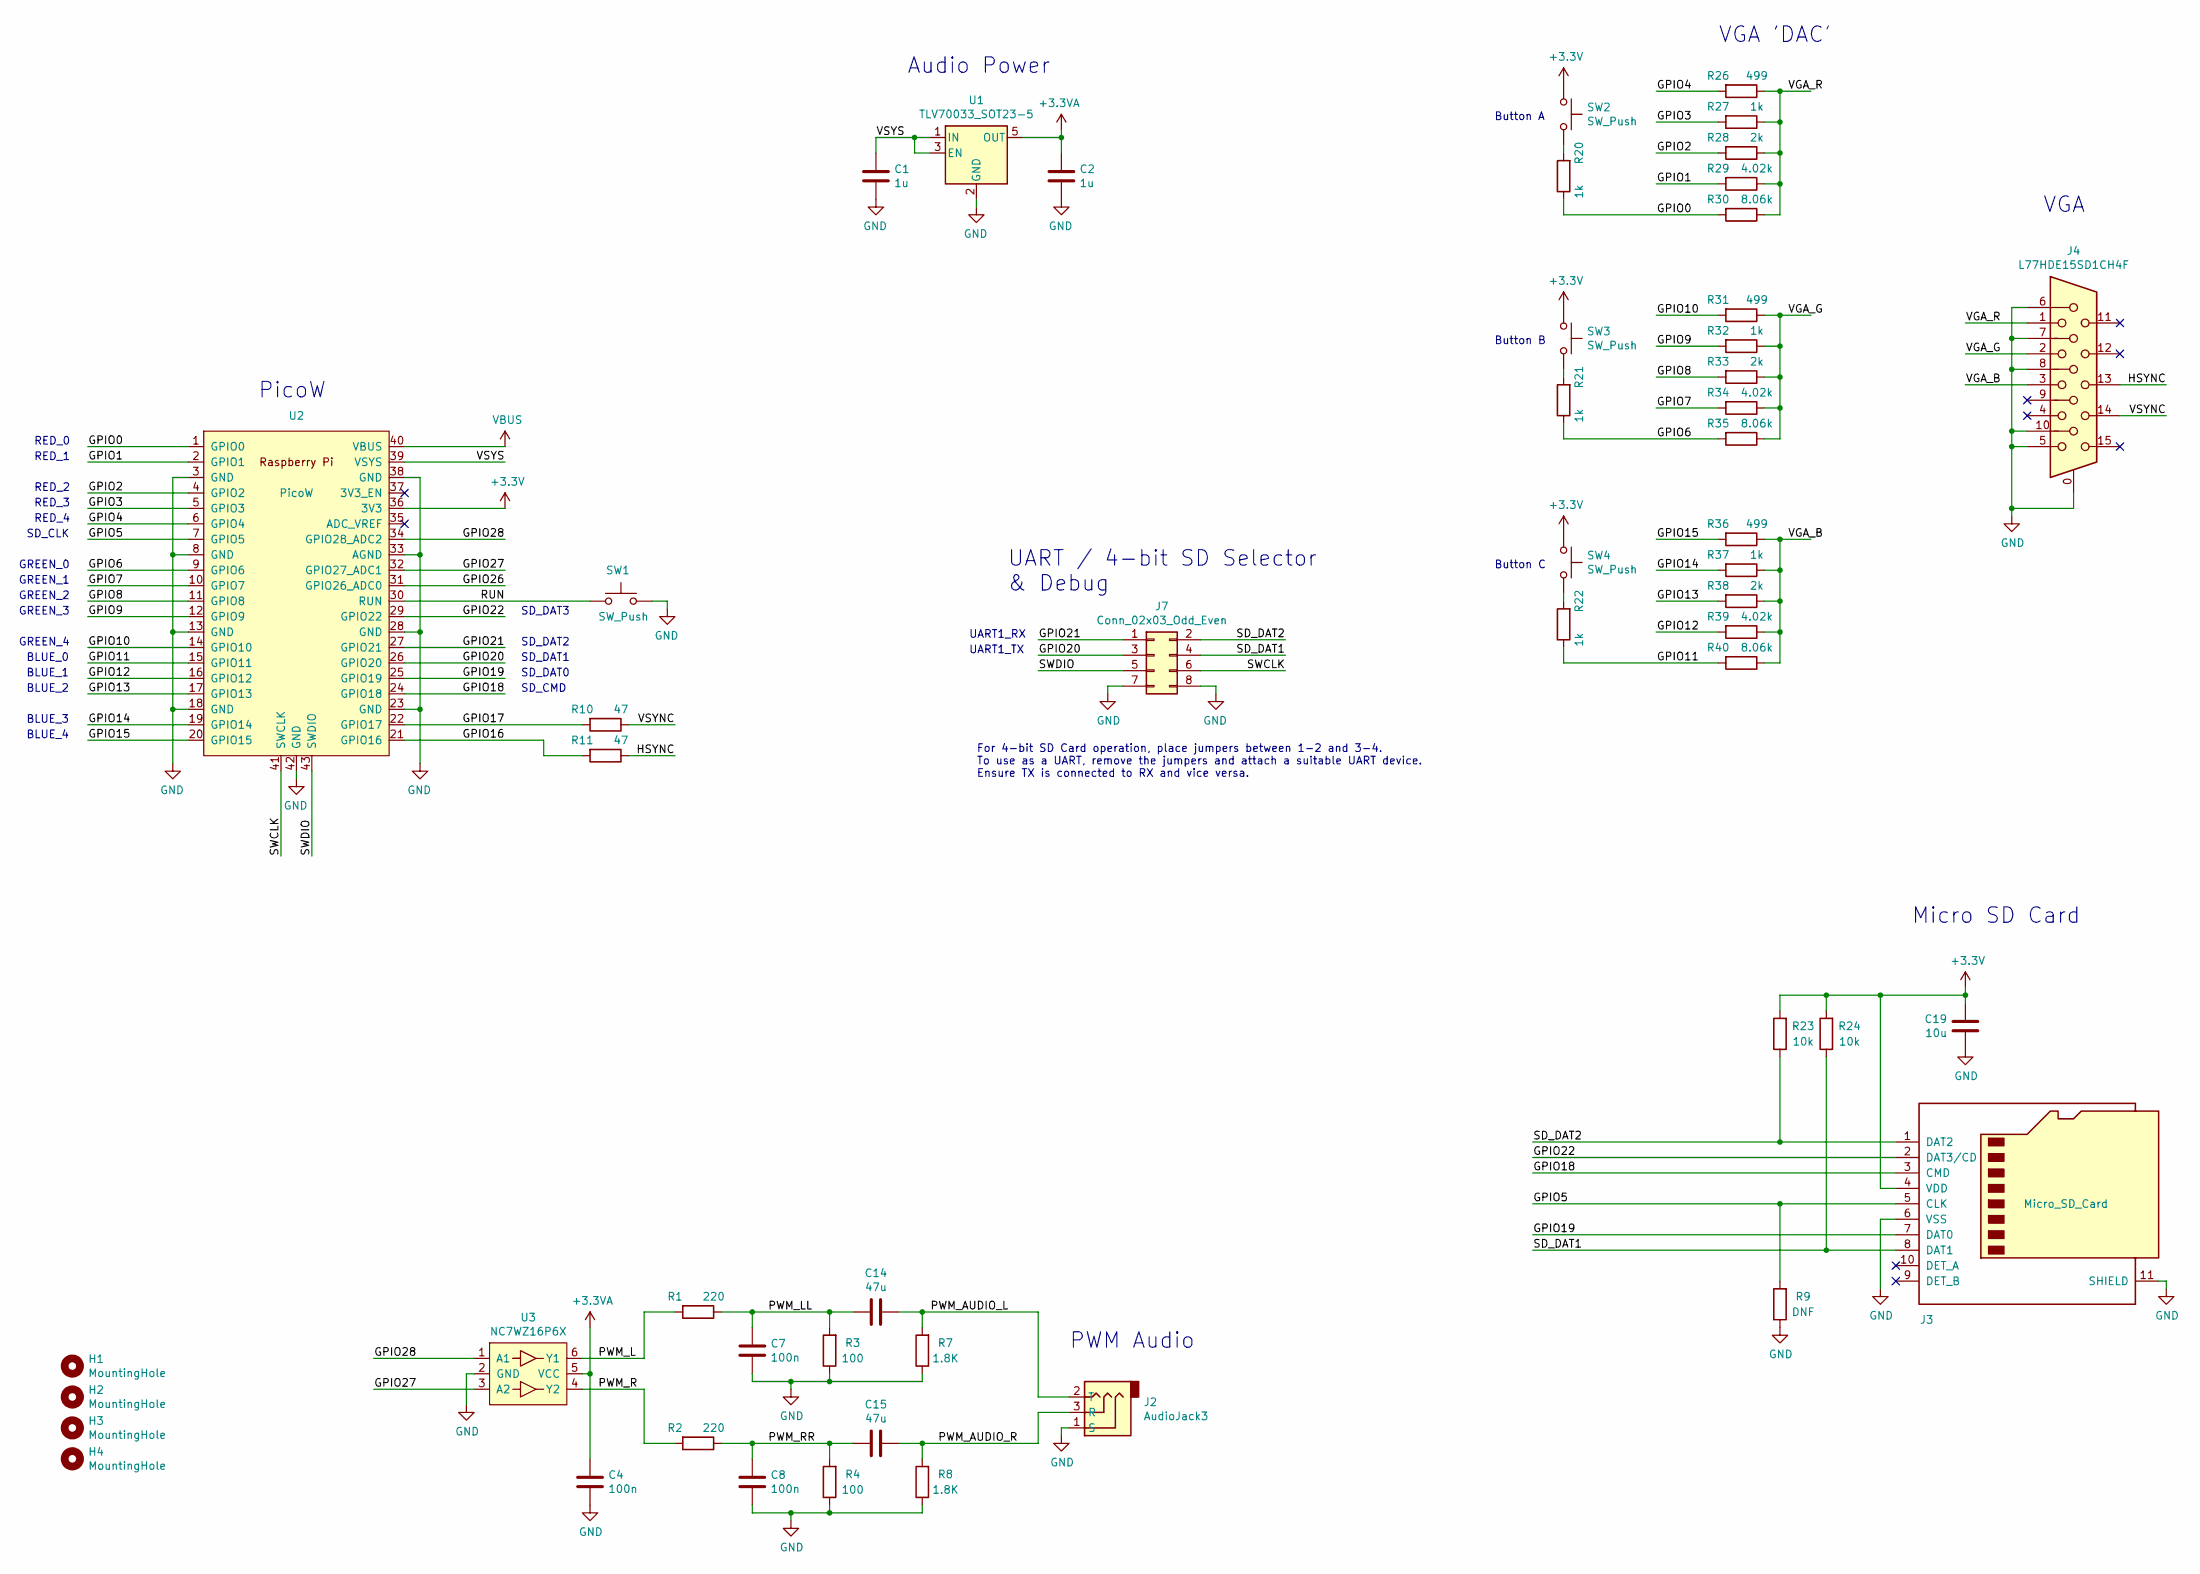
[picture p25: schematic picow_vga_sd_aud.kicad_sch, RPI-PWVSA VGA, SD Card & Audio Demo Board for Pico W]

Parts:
C1, C2: 1u; C_0603_1608Metric
C4, C7, C8: 100n; C_0402_1005Metric
C14, C15: 47u; C_0805_2012Metric
C19: 10u; C_0603_1608Metric
H1, H2, H3, H4: MountingHole; MountingHole_2.7mm_M2.5
J2: AudioJack3; CUI_SJ-3523-audio-jack
J3: Micro_SD_Card; microSD_HC_Molex_104031-0811
J4: L77HDE15SD1CH4F; DSUB-15-L77HDE15SD1CH4F
J7: Conn_02x03_Odd_Even; PinHeader_2x04_P2.54mm_Vertical
R1, R2: 220; R_0402_1005Metric
R3, R4: 100; R_0402_1005Metric
R7, R8: 1.8K; R_0402_1005Metric
R9: DNF; R_0402_1005Metric
R10, R11: 47; R_0402_1005Metric
R20, R21, R22, R27, R32, R37: 1k; R_0402_1005Metric
R23, R24: 10k; R_0402_1005Metric
R26, R31, R36: 499; R_0402_1005Metric
R28, R33, R38: 2k; R_0402_1005Metric
R29, R34, R39: 4.02k; R_0402_1005Metric
R30, R35, R40: 8.06k; R_0402_1005Metric
SW1, SW2, SW3, SW4: SW_Push; SW_Push_1P1T_NO_Vertical_Wuerth_434133025816
U1: TLV70033_SOT23-5; SOT-23-5
U2: PicoW; RPi_PicoW_SMD_TH
U3: NC7WZ16P6X; SOT-363_SC-70-6

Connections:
+3.3VA: C2.1, C4.1, U1.5 (OUT), U3.5 (VCC)
+3V3: C19.1, J3.4 (VDD), R23.2, R24.2, SW2.1, SW3.1, SW4.1, U2.36 (3V3)
/GPIO0: R20.1, R30.2, U2.1 (GPIO0)
/GPIO1: R29.2, U2.2 (GPIO1)
/GPIO2: R28.2, U2.4 (GPIO2)
/GPIO3: R27.2, U2.5 (GPIO3)
/GPIO4: R26.2, U2.6 (GPIO4)
/GPIO5: J3.5 (CLK), R9.2, U2.7 (GPIO5)
/GPIO6: R21.1, R35.2, U2.9 (GPIO6)
/GPIO7: R34.2, U2.10 (GPIO7)
/GPIO8: R33.2, U2.11 (GPIO8)
/GPIO9: R32.2, U2.12 (GPIO9)
/GPIO10: R31.2, U2.14 (GPIO10)
/GPIO11: R22.1, R40.2, U2.15 (GPIO11)
/GPIO12: R39.2, U2.16 (GPIO12)
/GPIO13: R38.2, U2.17 (GPIO13)
/GPIO14: R37.2, U2.19 (GPIO14)
/GPIO15: R36.2, U2.20 (GPIO15)
/GPIO16: R11.2, U2.21 (GPIO16)
/GPIO17: R10.2, U2.22 (GPIO17)
/GPIO18: J3.3 (CMD), U2.24 (GPIO18)
/GPIO19: J3.7 (DAT0), U2.25 (GPIO19)
/GPIO20: J7.3, U2.26 (GPIO20)
/GPIO21: J7.1, U2.27 (GPIO21)
/GPIO22: J3.2 (DAT3/CD), U2.29 (GPIO22)
/GPIO26: U2.31 (GPIO26_ADC0)
/GPIO27: U2.32 (GPIO27_ADC1), U3.3 (A2)
/GPIO28: U2.34 (GPIO28_ADC2), U3.1 (A1)
/HSYNC: J4.13, R11.1
/PWM_AUDIO_L: C14.1, J2.2 (T), R7.2
/PWM_AUDIO_R: C15.1, J2.3 (R), R8.2
/PWM_L: R1.2, U3.6 (Y1)
/PWM_LL: C7.1, C14.2, R1.1, R3.2
/PWM_R: R2.2, U3.4 (Y2)
/PWM_RR: C8.1, C15.2, R2.1, R4.2
/RUN: SW1.1, U2.30 (RUN)
/SD_DAT1: J3.8 (DAT1), J7.4, R24.1
/SD_DAT2: J3.1 (DAT2), J7.2, R23.1
/SWCLK: J7.6, U2.41 (SWCLK)
/SWDIO: J7.5, U2.43 (SWDIO)
/VGA_B: J4.3, R36.1, R37.1, R38.1, R39.1, R40.1
/VGA_G: J4.2, R31.1, R32.1, R33.1, R34.1, R35.1
/VGA_R: J4.1, R26.1, R27.1, R28.1, R29.1, R30.1
/VSYNC: J4.14, R10.1
/VSYS: C1.1, U1.1 (IN), U1.3 (EN), U2.39 (VSYS)
GND: C1.2, C2.2, C4.2, C7.2, C8.2, C19.2, J2.1 (S), J3.6 (VSS), J3.11 (SHIELD), J4.0, J4.5, J4.6, J4.7, J4.8, J4.10, J7.7, J7.8, R3.1, R4.1, R7.1, R8.1, R9.1, SW1.2, U1.2 (GND), U2.3 (GND), U2.8 (GND), U2.13 (GND), U2.18 (GND), U2.23 (GND), U2.28 (GND), U2.33 (AGND), U2.38 (GND), U2.42 (GND), U3.2 (GND)
unnamed: R20.2, SW2.2
unnamed: R21.2, SW3.2
unnamed: R22.2, SW4.2
VBUS: U2.40 (VBUS)

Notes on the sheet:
GREEN_0
RED_3
RED_1
SD_DAT2
Button A
VGA
SD_CLK
BLUE_4
BLUE_0
UART1_TX
SD_DAT1
RED_4
PicoW
For 4-bit SD Card operation, place jumpers between 1-2 and 3-4. To use as a UART, remove the jumpers and attach a suitable UART device. Ensure TX is connected to RX and vice versa.
UART1_RX
VGA 'DAC'
Button B
Button C
GREEN_1
UART / 4-bit SD Selector & Debug
SD_DAT0
BLUE_3
SD_CMD
SD_DAT3
Micro SD Card
GREEN_4
RED_2
GREEN_2
Audio Power
PWM Audio
BLUE_1
GREEN_3
BLUE_2
RED_0

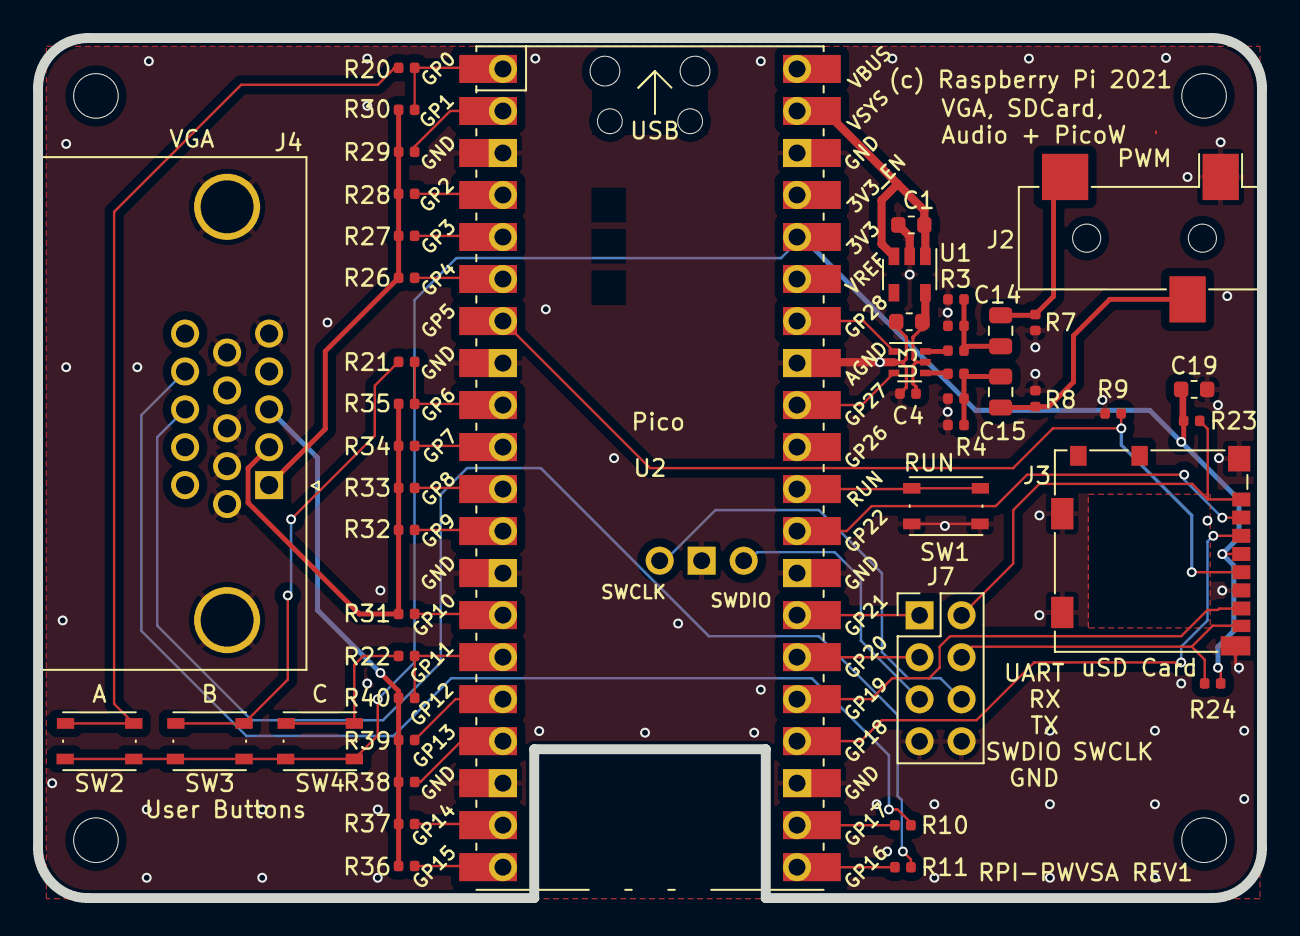
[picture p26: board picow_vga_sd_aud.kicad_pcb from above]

Board: 4 copper layers, 74.0 x 52.0 mm, 52 parts (0 on the bottom side), 48 nets.

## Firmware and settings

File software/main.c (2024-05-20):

/*
 *
 * Copyright (c) 2024 Andrey Ezhkov
 *
 */

#include <stdio.h>
#include "pico/stdlib.h"
#include "hardware/pwm.h"
#include "hardware/irq.h"
#include "hardware/pio.h"
#include "hardware/timer.h"
#include "pico/binary_info.h"
#include "pico/cyw43_arch.h"
#include "lwip/udp.h"
#include "lwip/ip_addr.h"

//  PIN DEFINITIONS
//  FRONT LEG
#define FRONT_FEMUR_IN1_PIN 0
#define FRONT_FEMUR_IN2_PIN 1
#define FRONT_KNEE_IN1_PIN 2
#define FRONT_KNEE_IN2_PIN 3
#define FRONT_FEMUR_EA_PIN 8
#define FRONT_FEMUR_EB_PIN 9
#define FRONT_KNEE_EA_PIN 10
#define FRONT_KNEE_EB_PIN 11
//  BACK LEG
#define BACK_FEMUR_IN1_PIN 4
#define BACK_FEMUR_IN2_PIN 5
#define BACK_KNEE_IN1_PIN 6
#define BACK_KNEE_IN2_PIN 7
#define BACK_FEMUR_EA_PIN 12
#define BACK_FEMUR_EB_PIN 13
#define BACK_KNEE_EA_PIN 14
#define BACK_KNEE_EB_PIN 15

#define MAX_PWM 100
#define MIN_PWM 60

//SERVO CONTROL
#define KP 5

#define UDP_SERVER_PORT 12345
#define BEACON_MSG_LEN_MAX 127
#define BEACON_TARGET "255.255.255.255"
#define BEACON_INTERVAL_MS 1000

#define DEVICE_ID 1 // or 1

#if DEVICE_ID == 0
        #define MAX_ANGLE -42
#else
        #define MAX_ANGLE 42 // max angle = 99.47368423
#endif
#define MIN_ANGLE 0
//PWM 
uint wrapP = 12500;
  
// Arrays for motor variables
// Motor index to pin
const uint motorIndexToPins[4][4] = { 
  {FRONT_FEMUR_IN1_PIN, FRONT_FEMUR_IN2_PIN, FRONT_FEMUR_EA_PIN, FRONT_FEMUR_EB_PIN}, 
  {FRONT_KNEE_IN1_PIN, FRONT_KNEE_IN2_PIN, FRONT_KNEE_EA_PIN, FRONT_KNEE_EB_PIN}, 
  {BACK_FEMUR_IN1_PIN, BACK_FEMUR_IN2_PIN, BACK_FEMUR_EA_PIN, BACK_FEMUR_EB_PIN}, 
  {BACK_KNEE_IN1_PIN, BACK_KNEE_IN2_PIN, BACK_KNEE_EA_PIN, BACK_KNEE_EB_PIN}
};

//ENCODERS
int QEM [16] = {0,-1,1,2,1,0,2,-1,-1,2,0,1,2,1,-1,0}; // Quadrature Encoder Matrix // Old * 4 + New //state machine

/* struct axis
 * /brief handles variable for a motor
 *
 * keeps track of its position via count. keeps track of its P control variables via 6 variables
 *
 */
struct axis {
        // Counts the encoder changes in total. Can be used to calculate absolute position since start
        int count;
        int oldState;
        int newState;

        // P control
        uint8_t moving;
        int direction;
        int setPoint;
        int startPoint;
        int error;
        int P;
};
// Motor index to struct
struct axis axes[4];
struct axis *p;

int led;
int input_data[26]; 

/* long map()
 * /brief basic map function
 * 
 */
long map(long x, long in_min, long in_max, long out_min, long out_max)
{
  	return (x - in_min) * (out_max - out_min) / (in_max - in_min) + out_min;
} 


/* void driveMotor()
 * /brief controls a motor based on 3 inputs
 * 
 * this function decides the target motor, considers the enable value and calculates output PWM signals that are then written to the output control pins
 * 
 */
void driveMotor(int motorIndex, int driveValue, bool driveEnable){
        // Get target PWM slices
       	uint femurSlice = pwm_gpio_to_slice_num(motorIndexToPins[motorIndex][0]);
        uint kneeSlice = pwm_gpio_to_slice_num(motorIndexToPins[motorIndex][1]);
        // Check if the motor should be moved
        if(driveEnable){
                // Calculate input 1 & 2
                double pwmIn1, pwmIn2;
                if(driveValue == 0){
                        // Brake
                        pwmIn1 = 100;
                        pwmIn2 = 100;
                }
                else if(driveValue > 0){
                        pwmIn1 = driveValue;
                        pwmIn2 = 0;
                }
                else{
                        pwmIn1 = 0;
                        pwmIn2 = driveValue*-1;
                }
                // Write to pins
                // pwmIn1
		pwm_set_chan_level(femurSlice, PWM_CHAN_A, wrapP * (pwmIn1/100) );
                // pwmIn2
		pwm_set_chan_level(kneeSlice, PWM_CHAN_B, wrapP * (pwmIn2/100) );
        }
}

/* void process_data()
 * /brief decodes the message into tasks for the motors
 * 
 * based on the control message structure this code decodes the input_data[] array (received data) into instructions for each motor
 * 
 */
void process_data(){
        int dir;
        struct axis *j;
        
        if (DEVICE_ID == 0) {
                for (int i = 0; i < 4; i++) {
                        //direction on the left side is  inverted
                        //level inner servo
                        dir = (input_data[(i*3) + 1] == 1) ? 1 : -1; 
                
                        j = axes+i;
                        
            	        j->startPoint = j->count;
                        j->setPoint = j->startPoint + (dir * (10*input_data[(i*3) + 2] + input_data[(i*3) + 3])); 
                        
                        //direction on the left side is inverted
                        if(MAX_ANGLE < j->setPoint && j->setPoint < MIN_ANGLE){
	                        j->moving = true;
                                // DEBUG
                                //if ( opt.verbose && opt.verboseDataRCV){ printf("moving \n"); }
                                printf("moving \n");
                        }
                }
        }
        else {
                for (int i = 0; i < 4; i++) {
                        
                        dir = (input_data[(i*3) + 1 + 13] == 1) ? -1 : 1; 
                
                        j = axes+i;
                        
            	        j->startPoint = j->count;
                        j->setPoint = j->startPoint + (dir * (10*input_data[(i*3) + 2 + 13] + input_data[(i*3) + 3 + 13])); 
                        
                        printf("dir * (10*input_data[(i*3) + 2 + 13] + input_data[(i*3) + 3 + 13]) %d \n", dir * (10*input_data[(i*3) + 2 + 13] + input_data[(i*3) + 3 + 13]) );
                        printf("j->setPoint %d \n", j->setPoint);
                                
                        if(MAX_ANGLE > j->setPoint && j->setPoint > MIN_ANGLE){
                                j->moving = true;
                                printf("moving \n");
                        }
                        
                }
        }
        
}

/* void udp_receive_callback()
 * /brief handles the received data from UDP
 * 
 * this function is being called every time the poll has detected anything sent via UDP
 * checks if the message is the right length. parses it to an array input_data[]. then switches the state of a LED and frees the buffer
 * 
 */
void udp_receive_callback(void *arg, struct udp_pcb *pcb, struct pbuf *p, const ip_addr_t *addr, u16_t port) {
        if (p != NULL) {
                // Received packet buffer 'p' is not NULL
                // You can process the packet here
                char *packet_data = (char *)p->payload;
                
                if (strlen(packet_data) == 52) {
                        int i;
                        
                        while (packet_data[i] != '\0' && packet_data[i+1] != '\0') {
                                input_data[i/2] = ((packet_data[i] - '0') * 10 + (packet_data[i+1] - '0')) - 30;
                                printf("%d\n", input_data[i/2]);
                                i += 2;
                        }
                        
                        process_data();
                }
                
                // Toggle led
                led = led ^ 1;
                cyw43_arch_gpio_put(CYW43_WL_GPIO_LED_PIN, led);

                // Don't forget to free the packet buffer
                pbuf_free(p);
        }
}

/* void on_pwm_wrap()
 * /brief inner control loop and encoder assesment
 * 
 * this function is being called with the frequency of the PWM (10KHz)
 * firstly it clears the interrupt flag
 * then it runs a for loop for the each of the 4 encoders. inside it calculates if there are any changes to the recorded position via the encoder matrix
 * then it runs a for loop for the each of the 4 motors. this is the P control. inside it calculates if there are any changes to the set point of the motor and if
 * it calculates a error and P change which is being sent to the motor via PWM
 * 
 */
void on_pwm_wrap() {
//NO PRINT F INSIDE OF THIS FUNCTION!
//there is not enough time to execute and clogs the program!

        // Clear the interrupt flag that brought us here
        pwm_clear_irq(pwm_gpio_to_slice_num(motorIndexToPins[0][0]));
        
        for (int i = 0; i < 4; i++) {
                p = axes+i;
                
                p->oldState = p->newState;
        	p->newState = gpio_get(motorIndexToPins[i][3])*2 + gpio_get(motorIndexToPins[i][2]);
        	
        	//illegal case check
        	if (QEM[ p->oldState*4 + p->newState ] == 2) {
                        //brake
                        p->moving = false;
                        driveMotor(i, 0, true);
        	}
        	else {  
                	p->count += QEM[p->oldState*4 + p->newState]; 
        	}
        }
        
        for (int i = 0; i < 4; i++) {
        //XXX INTERNAL SERVO CONTROL LOOP NOW WORKS WITH COUNT NOT EXACT ANGLE POSITION
                p = axes+i;
                
	        if ( p->moving ){
         		p->direction = (p->setPoint - p->startPoint != 0) ? ((p->setPoint - p->startPoint > 0) ? 1 : -1) : 0; 
            		if(p->direction != 0){

                                p->error = p->setPoint - p->count;

                                p->P = KP * p->error;
                                
                                if(p->direction == 1){             
                                        if(p->P >= p->setPoint - p->startPoint){
                                                p->P = MAX_PWM;
                                        }
                                        else{
                                                p->P = map(p->P,
                                                0, p->setPoint - p->startPoint,
                                                MIN_PWM, MAX_PWM);
                                        }
                                }
                                else if(p->direction == -1){         
                                        if(p->P <= p->setPoint - p->startPoint){
                                                p->P = MAX_PWM;
                                        }
                                        else{
                                                p->P = map(p->P,
                                                0, p->setPoint - p->startPoint,
                                                MIN_PWM, MAX_PWM);
                                        }
                                        p->P*=-1;
                                }
                                //if ( !opt.disableMovement ){
                                        driveMotor(i, p->P, true); 
                                //}
		        }
		        else{
                          driveMotor(i, 0, true); 
		          p->moving = false;
		        }
         	}
	        else{
                        driveMotor(i, 0, true); 
	        }
 	}
}

/* void initPins()
 * /brief initializes the pins
 * 
 * the function runs a for loop 4 times as for the number of motors. for each motor initializes 2 pins with 10KHz PWM for output control. then initializes 2 more pins as input for the encoder
 * at last creates a PWM interrupt that fires on the PWM frequency and appoints on_pwm_wrap() to be executed on each IRQ
 * 
 */
void initPins(){

        for (int i = 0; i < 4; i++) {
                // Motor control pins
                // Set up pwm on GPIO pin for IN1
                gpio_set_function(motorIndexToPins[i][0], GPIO_FUNC_PWM);
                // Enable PWM on that channel
                pwm_set_enabled(pwm_gpio_to_slice_num(motorIndexToPins[i][0]), true);
                // Set wrap point
                pwm_set_wrap(pwm_gpio_to_slice_num(motorIndexToPins[i][0]), wrapP);
                
                // Set up pwm on GPIO pin for IN2
                gpio_set_function(motorIndexToPins[i][1], GPIO_FUNC_PWM);
                // Enable PWM on that channel
                pwm_set_enabled(pwm_gpio_to_slice_num(motorIndexToPins[i][1]), true);
                // Set wrap point
                pwm_set_wrap(pwm_gpio_to_slice_num(motorIndexToPins[i][1]), wrapP);
                
                // Encoder pubs
                // Set up the reading pin CHAN A
                gpio_init(motorIndexToPins[i][2]);
                gpio_set_dir(motorIndexToPins[i][2], GPIO_IN);
                // Set up the reading pin CHAN B
                gpio_init(motorIndexToPins[i][3]);
                gpio_set_dir(motorIndexToPins[i][3], GPIO_IN);
        }
    
        //servo control interrupt 
        // the interrupt is with the pwm wrap frequency
        pwm_clear_irq(pwm_gpio_to_slice_num(motorIndexToPins[0][0]));
        pwm_set_irq_enabled(pwm_gpio_to_slice_num(motorIndexToPins[0][0]), true);
        irq_set_exclusive_handler(PWM_IRQ_WRAP, on_pwm_wrap);
        irq_set_enabled(PWM_IRQ_WRAP, true);
        pwm_config config = pwm_get_default_config();
}

/* int init_wireless()
 * /brief initializes the wireless interface
 * 
 * calls cyw43_arch_init() which inits the wireless hardware and returns an error code. 
 * then enables the wireless ap via cyw43_arch_enable_sta_mode(). cyw43_arch_wifi_connect_timeout_ms() tries to connect to a wifi network with a name and a password.
 * an LED lights up if its connected. the code then creates an udp instance via udp_new().
 * finally a connection is made to broadcast (255.255.255.255) and the protocol is being binded. udp_receive_callback() is being appointed to be called when there is udp activity.
 * 
 */
int init_wireless(){
        if (cyw43_arch_init()) {
                printf("failed to initialise\n");
                return 1;
        }

        cyw43_arch_enable_sta_mode();

        if (cyw43_arch_wifi_connect_timeout_ms("andrey_shefa", WIFI_PASSWORD, CYW43_AUTH_WPA2_AES_PSK, 30000)) {
                return 1;
        } else {
                led = led ^ 1;
                cyw43_arch_gpio_put(CYW43_WL_GPIO_LED_PIN, led);
        }

        struct udp_pcb *udp_server_pcb = udp_new();
        if (udp_server_pcb == NULL) {
                return -1;
        }

        ip_addr_t ipaddr;
        IP4_ADDR(&ipaddr, 255,255,255,255); // Broadcast address

        err_t err = udp_bind(udp_server_pcb, &ipaddr, UDP_SERVER_PORT);
        if (err != ERR_OK) {
                printf("Failed to bind UDP server PCB.\n");
                return -1;
        }

        udp_recv(udp_server_pcb, udp_receive_callback, NULL);
}

/* int main()
 * /brief starts the program, calls stdio_init_all(), init_wireless(), initPins()
 * 
 * the main loop is with the lowest computing priority. it's function is to non-stop loop the cyw43_arch_poll() function which polls the wireless. 
 * the main loop has no constant 'polling rate' because of its low priority and therefore it uses all left processor time from the high priority code in the PWM IRQ 
 */
int main() {
   	stdio_init_all();
    	
    	init_wireless();

	initPins();
	
    	while (true) {
                cyw43_arch_poll();
    	} 
    	
        cyw43_arch_deinit();
        return 0;
}

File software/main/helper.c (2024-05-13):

//FIXME: FOR TESTING PHOTO COUPLES
void encoderCallback(uint gpio, uint32_t events) {   
    if (gpio == motorIndexToPins[0][2] || gpio == motorIndexToPins[0][3]){
        if(gpio==motorIndexToPins[0][2]){
          if (events == GPIO_IRQ_EDGE_RISE){
            gpio_put(20, 1);
          }
          else{
            gpio_put(20, 0);
          }
        }
        if(gpio==motorIndexToPins[0][3]){
          if (events == GPIO_IRQ_EDGE_RISE){
            gpio_put(19, 1);
          }
          else{
            gpio_put(19, 0);
          }
        }
    	
    }    
}

//-------------------------------

void keyboardControl(){
        int input = 0;
        
        printf("Axis [ 1 ] count: %d \n", axes[1].count);
        printf("Error: %d \n", axes[1].error);
        printf("P: %d \n", axes[1].P);
        printf("Axis [ 1 ] count: %d \n", axes[1].count);

        printf("Enter direction [0 || 1] (1 = -1): \n");
        input = getchar() - 48;
        input = (input == 0 || input == 1) ? ((input == 0) ? 1 : -1) : 0; 

        printf("Enter target count Xx: \n");
        input = input*(getchar() - 48)*10;
        printf("Enter target count xX: \n");
        input += getchar() - 48;
        printf("Target count: %d \n", input);

        axes[1].startPoint = axes[1].count;
        axes[1].setPoint = axes[1].startPoint + input; 
        if(MAX_ANGLE > axes[1].setPoint && axes[1].setPoint > MIN_ANGLE){
	          		axes[1].moving = true;
        }
        sleep_ms(1000);
        
        //printf("Enter angle motor index [0 || 1]: \n");
        //input = getchar() - 48;

	//if (input == 0) {
        //	printf("FEMUR \n");
	//}
	//sleep_ms(1111);
}

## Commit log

2023-10-03 added motor model
    [leg.FCStd, xd-37gb520-Body.stl, xd-37gb520.FCStd]
2023-10-06 working on the hip
    [hip-lower.FCStd, hip-upper-shell.stl, hip.FCStd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]
2023-10-06 working on hip lower
    [hip-lower.FCStd]
2023-10-07 working on the hip reworked
    [hip-lower.FCStd, hip-upper-shell.stl, hip.FCStd]
2023-10-07 finished hip-lower
    [hip-lower-Body.stl, hip-lower.FCStd]
2023-10-10 added knee
    [knee.FCStd, knee.stl]
2023-10-10 added femur
    [femur.FCStd, femur.stl]
2023-10-10 reworked leg and motor renders
    [femur.FCStd, femur.stl, leg.FCStd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]
2023-10-10 added knee drive
    [knee-drive.FCStd, knee-drive.stl, leg.FCStd]
2023-10-18 finished updated femur and knee redisign
    [belt-gear.FCStd, femur-left.FCStd, femur-left.stl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]
2023-10-26 added encoder base body
    [base.FCStd, belt-gear.stl, femur-right.FCStd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]
2023-11-23 have been working on the driver
    [hip-sensor-cap-Body.stl, hip-sensor-cap.FCStd, motor-driver.kicad_sch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]
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2023-12-13 added single encoder
    [encoder-wheel-8-1mm.FCStd, encoder-wheel-8-1mm.stl, encoder-wheel-8-3mm.FCStd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]
2023-12-17 added single encoder servo code
    [encoder-gear-Body.stl, encoder-gear.FCStd, encoder-wheel-8-1mm.FCStd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]
2023-12-22 improved encoder design
    [encoder-gear-Body.stl, encoder-gear.FCStd, ledCover-Body.stl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]
2023-12-23 refining the encoder wheel and hip cap
    [hip-sensor-cap-Body.stl, hip-sensor-cap.FCStd, wing.FCStd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]
2023-12-26 added quadrature encoder software
    [hip-sensor-cap-68.stl, wingFull.FCStd, wingFull.stl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]
2023-12-26 added self made quadrature software for positioning
    [hip-sensor-cap-224.stl]
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2023-12-27 trying to confine quadrature encoder to one sm
2023-12-28 daily backup
    [femur-left-light.stl, femur-left.FCStd, hip-sensor-cap.FCStd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]
2023-12-28 reorganized the repo
    [base.FCStd, belt-gear.FCStd, encoder-gear-Body.stl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]
2023-12-28 new knee design
    [knee-first-iteration.FCStd, knee-left.FCStd, knee-left.stl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]
2023-12-28 returned old knee and redesigned hip lower
    [hip-lower-Body.stl, hip-lower-old.FCStd, hip-lower.FCStd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]
2024-01-02 started writing leg controller code (currently not working)
    [hip-cap-support-Body.stl, hip-cap-support.FCStd, hip-lower-patch-Body.stl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]
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2024-01-04 working on new femur
    [femur-Body-Mirror.stl, femur-old.FCStd, femur.FCStd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]
2024-01-04 finished the new femur
    [femur-Body-Mirror.stl, femur-other-side.FCStd, femur-other-side.stl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]
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2024-01-18 fixed pwm irq reinit bug
    [main.c]
2024-01-19 some questionable hole counting (doesn not work)
    [main.c]
2024-01-19 working reverse inner loop servo control in debug mode
    [main.c]
2024-01-19 working reverse inner loop servo control @ 10kHz
    [main.c]
2024-01-21 added encoder maxmin position check
    [wingCut.FCStd, wingCut.stl, wingFull.FCStd]
2024-01-21 added femur encoder shell
    [hip-encoder-shell.stl, hip-sensor-cap-Body.stl, hip-sensor-cap.FCStd]
2024-01-25 separated control loop obligations
    [hip-encoder-shell.stl, hip-sensor-cap.FCStd]
2024-01-26 redowing the knee movement mechanism
    [knee-drive.FCStd, knee-drive.stl, knee-left.FCStd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]
2024-01-27 redesigning leg
    [drive-ring-Body.stl, drive-ring.FCStd, femur-Body-Mirror.stl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]
2024-01-29 refing the new leg design
    [drive-ring-Body.stl, drive-ring.FCStd, knee-drive.FCStd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]
2024-01-30 almost done with the redesign
    [btens10.FCStd, btens10.stl, btens14.stl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]
2024-01-30 finalizing the design
    [body.FCStd, btens10.FCStd, btens10.stl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]
2024-02-02 more refinement
    [belt-gear-Body.stl, belt-gear.FCStd, gear-pin.stl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]
2024-02-03 non-stop design renfinement'
    [belt-keep-ring-Body.stl, belt-keep-ring.FCStd, hip-sensor-cap.FCStd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]
2024-02-03 femur finished
    [femur-drive-gear-Body.stl, femur-drive-gear.stl, femur-inner-Body.stl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]
2024-02-04 fucking encodr works again (returned to metal foil)
    [femur-inner.FCStd, hip-encoder-shell-long-proper.stl, hip-encoder-shell-long.stl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]
2024-02-04 started working on the mandatory pcb
    [fake-platka.kicad_pcb, fake-platka.kicad_sch, leg-electronics.kicad_sch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]
2024-02-05 starting to write the documentation
    [fake-platka.kicad_sch, leg-electronics.kicad_sch]
2024-02-05 made first pcb
    [RaspberryPi-PicoW-NoPins.step, fake-platka.csv, fake-platka.kicad_pcb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]
2024-02-06 added all components to the schematic and pcb
    [fake-platka.kicad_pcb, fake-platka.kicad_sch, left_controller.kicad_sch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]
2024-02-09 working on pcb and documentation
    [fake-platka-B_Cu.gbr, fake-platka-B_Mask.gbr, fake-platka-B_Paste.gbr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]
2024-02-12 board finished
    [fake-platka-half-route.kicad_pcb, fake-platka.kicad_pcb]
2024-02-14 finalizing the documentation
    [fake-platka.kicad_pcb]
2024-02-15 added experimental encoder masks
    [encoder_mask_proper.dwg, encoder_mask_wrong.dwg]
2024-02-17 finished hip upper
    [body-hips.FCStd, encoder_mask_proper.dxf, encoder_mask_wrong.dxf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]
2024-02-17 added body mounts
    [body-hips.FCStd, hip-lower-BL.stl, hip-lower-BR.stl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]
2024-02-18 added side lower
    [body-hips.FCStd, side-lower.FCStd, side-upper.FCStd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]
2024-02-18 added side upper
    [body-hips.FCStd, side-upper.FCStd, side-upper.stl]
2024-02-18 added parallel
    [body-hips.FCStd, parallel.FCStd, parallel.stl]
2024-02-18 added space for hip encoder cap and reallocated some m3 holes
    [body-hips.FCStd, hip-lower-BL.stl, hip-lower-BR.stl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]
2024-02-26 mutliple days of progress; documentation done; minor part adjustments
    [body-grouped.FCStd, body-hips.FCStd, fake-platka.csv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]
2024-02-26 minor adjustments
    [hip-lower-BL.stl, hip-lower-BR.stl, hip-lower-back.FCStd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]
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2024-03-07 added pos var reset and pio Y count reset
    [main.c]
2024-03-18 fixed dimensions of the knee drive
    [knee-drive.FCStd, knee-drive57.stl, knee-drive58.stl]
2024-03-18 body work
    [fake-platka-B_Cu.gbl, fake-platka-B_Mask.gbs, fake-platka-B_Paste.gbp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]
2024-04-03 added timer irq
    [58.stl, 59.stl, 60.stl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]
2024-04-04 CODE BROKEN started to rework the code, reallocating the encoder counting from pio to pwm irq
    [main.c]
2024-04-05 reworked the encoder reading
    [wingFullBelt.FCStd, wingFullBelt54.stl, wingFullBelt67.stl]
2024-04-07 working udp beacon
    [wingFullBelt.FCStd, wingFullBelt100.stl, wingFullBelt134.stl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]
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2024-05-07 reworked the graph leg movement
2024-05-07 fixed pitch
2024-05-09 fixed pitch leg addressation
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2024-05-20 polished the repo
    [body-grouped.FCStd, body-hips.FCStd]

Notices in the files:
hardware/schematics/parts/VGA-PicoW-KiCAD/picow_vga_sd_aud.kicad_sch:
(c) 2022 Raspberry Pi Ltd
